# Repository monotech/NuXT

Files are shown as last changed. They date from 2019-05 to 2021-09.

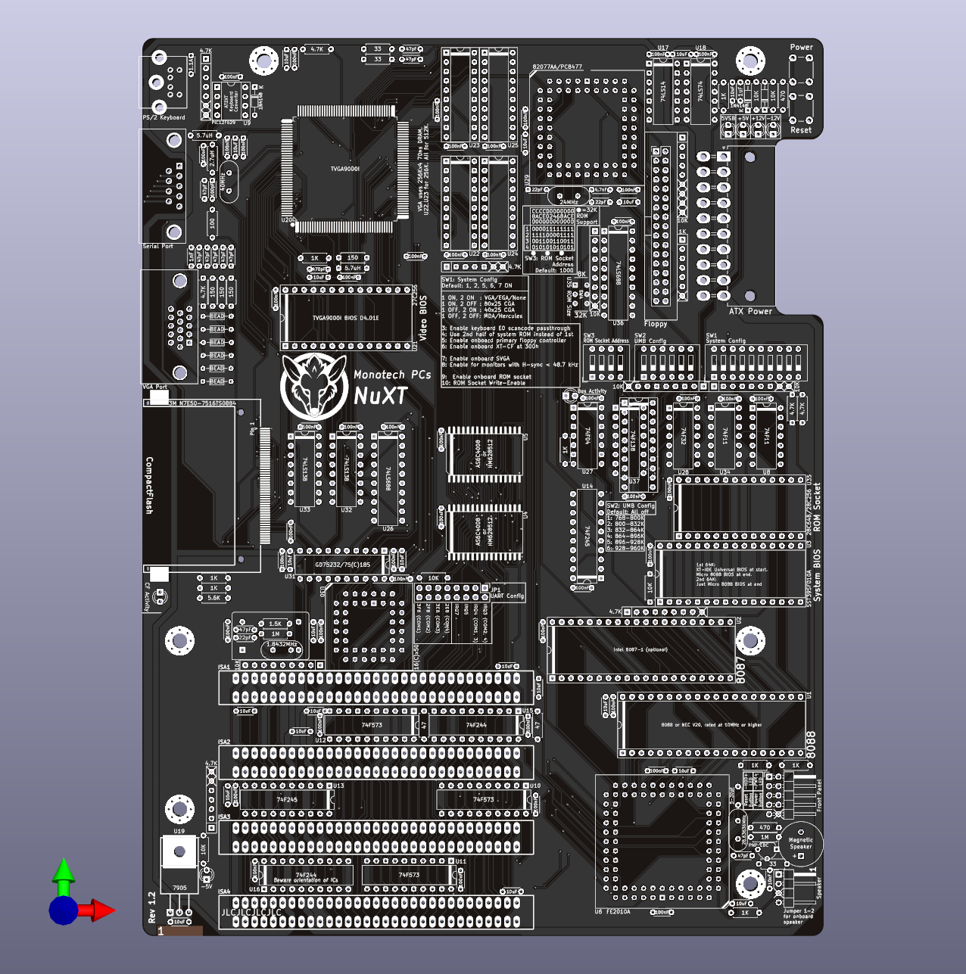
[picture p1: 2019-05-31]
Images/Top bare.png

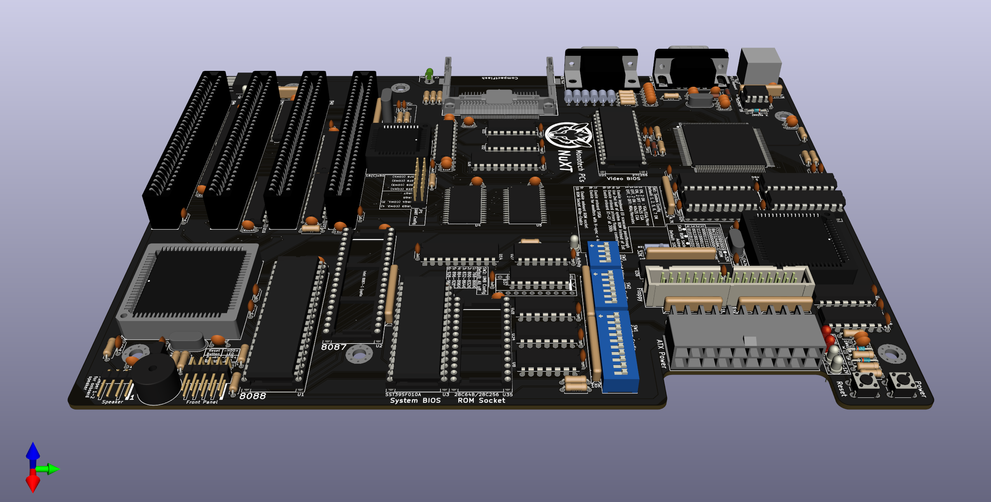
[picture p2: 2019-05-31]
Images/Inner side.png

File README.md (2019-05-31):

Based on schematics by Sergey Kiselev, with some small changes for combining optimization and board layout efficiency:

http://www.malinov.com/Home/sergeys-projects/isa-fdc-and-uart

http://www.malinov.com/Home/sergeys-projects/xt-cf-lite

http://www.malinov.com/Home/sergeys-projects/isa-supervga

https://github.com/skiselev/micro_8088

https://github.com/skiselev/isa8_backplane

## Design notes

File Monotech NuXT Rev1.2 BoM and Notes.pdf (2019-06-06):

## Monotech PCs NuXT Rev1.2 DIY Kit Instructions

These instructions are provided to help with this kit, but they do not show you how to make a good solder joint, or other electronics skills. If unsure, Google it, or ask. As with any DIY kit, warranty cannot be provided.

There are four surface mount components in this kit, with 1.27mm and 0.65mm pitch. Make sure you have good flux and are practiced in SMD soldering.

For troubleshooting, you should have a multimeter at the least; preferably an oscilloscope too.

## Parts list:

ICs | Package | Quantity | Markings/details | Needed for
FE2010A XT Chipset | LCC-84 | 1 | FE2010A*
Trident TVGA9000i VGA Chipset | QFP-160 | 1 | TVGA9000i-* | Onboard VGA
8088 or NEC V20 10MHz+ CPU | DIP-40 | 1 | *8088-1 or NEC D70108*-10
39SF010 128KiB 8-bit Flash (programmed) | DIP-32 | 1 | SST39SF010* (Micro 8088 BIOS + XT-IDE CF)
PIC12F629 Microcontroller (programmed) | DIP-8 | 1 | 12F629* (AT2XT Keyboard Converter) | PS/2 keyboard support
27C256 32KiB EPROM (programmed) | DIP-28-W | 1 | *27C256* (TVGA9000i BIOS D4.01E) | Onboard VGA
128KiB 4-bit 70ns DRAM | DIP-20 | 2 or 4 | *4C4256*70 or *514256*70 | Onboard VGA
512KiB 8-bit Parallel SRAM | SOP-32 450mil | 2 | AS6C4008-*SIN or HM628512*LFP*
PC8477 Floppy Controller | LCC-68 | 1 | PC8477* or 82077AA* | Onboard floppy controller
16550 UART | LCC-44 | 1 | *16*50* | Onboard serial port
75185 RS232 Transceiver | DIP-20 | 1 | *75*185* or GD75232* | Onboard serial port
74LS688 Identity Comparator | DIP-20 | 2 | *74*T688* or *74*S688* or *74F521* | Onboard XT-CF and ROM socket
74F573 Octal Latch | DIP-20 | 3 | *74F573*
74F245 Octal Transceiver | DIP-20 | 2 | *74F245*
74F244 Octal Buffer | DIP-20 | 2 | *74F244*
74F138 3-to-8 Decoder | DIP-16 | 1 | *74F138*
74LS138 3-to-8 Decoder | DIP-16 | 2 | *74*T138* or *74*S138* or *74F138* | Onboard floppy and serial
74LS74 Dual D Flip-flop | DIP-14 | 1 | *74*T74* or *74*S74* or *74F74*
74F32 Quad OR Gate | DIP-14 | 1 | *74F32*
74LS14 Schmitt Hex Inverter | DIP-14 | 1 | *74*T14* or *74*S14* or *74F14*
74F11 Triple 3-input AND Gate | DIP-14 | 2 | *74F11*
74HCT04 Hex Inverter | DIP-14 | 1 | *74*T04*
7905 Negative 5V Linear Regulator | TO-220 | 1 | *7905 | -5V rail at ISA slots
Crystals | Package | Quantity | Markings/details | Needed for
1.8432MHz Crystal | HC49* | 1 | Or a 5V DIP-14 Oscillator instead | Onboard serial port
24MHz Crystal | HC49* | 1 | | Onboard floppy controller
28.63636MHz Crystal | HC49* | 1
40MHz Crystal | HC49* | 1 | | Onboard VGA
Connectors | Package | Quantity | Markings/details | Needed for
2x31-way 2.54mm Through-hole edge connector | | 4 | | ISA slots
3M CompactFlash connector | | 1 | 3M N7E50-7516TS0884 | Onboard XT-CF
DE-9 Male right-angle connector | | 1 | Supports centred between both pin rows | Onboard serial port
DE-15 Female right-angle connector | | 1 | Supports in-line with middle pin row | Onboard VGA
6-pin Mini-DIN right-angle female connector | | 1 | Preferably purple | PS/2 keyboard support
4-way right-angle pin header | P=2.54mm | 1 | Speaker header | External speaker support
2x5-way right-angle pin header | P=2.54mm | 1 | Front panel header
2x8-way vertical pin header | P=2.54mm | 1 | Serial port jumper block | Onboard serial port
2x10-way right-angle male connector | P=4.2mm | 1 | ATX power connector
2x17-way vertical shrouded pin header | P=2.54mm | 1 | Floppy connector | Onboard floppy controller
DIP-8 Socket | | 1
DIP-20 Socket | | 4 | | Onboard VGA
DIP-28 Socket | | 2 | | Onboard VGA and ROM Socket
DIP-32 Socket | | 1
DIP-40 Socket | | 2
LCC-44 Through-hole Socket | | 1 | | Onboard serial port
LCC-68 Through-hole Socket | | 1 | | Onboard floppy controller
LCC-84 Through-hole Socket | | 1

Switches | Package | Quantity | Markings/details | Needed for
4-way DIP Switch | DIP-8 | 1 | ROM Socket Address | Onboard ROM socket
6-way DIP Switch | DIP-12 | 1 | UMB Config | UMB support
10-way DIP Switch | DIP-20 | 1 | System Config
MS-22D18G2 DPDT Switch | | 1 | U35 ROM Size | Onboard ROM socket
Standard Tactile Switch | | 2 | | Onboard Power / Reset button
Resistors | Package | Quantity | Markings/details | Needed for
33 Resistor | P=7.5mm | 3 | Org-Org-Blk or Org-Org-Blk-Gld
47 Resistor | P=7.5mm | 2 | Yel-Vil-Blk or Yel-Vil-Blk-Gld
100 Resistor | P=7.5mm | 1 | Brn-Blk-Brn or Brn-Blk-Blk-Blk | Onboard VGA
150 Resistor | P=7.5mm | 4 | Brn-Grn-Brn or Brn-Grn-Blk-Blk | Onboard VGA
470 Resistor | P=7.5mm | 2 | Yel-Vil-Brn or Yel-Vil-Blk-Blk
1K Resistor | P=7.5mm | 8 | Brn-Blk-Red or Brn-Blk-Blk-Brn
1.5K Resistor | P=7.5mm | 1 | Brn-Grn-Red or Brn-Grn-Blk-Brn | Onboard serial port
4.7K Resistor | P=7.5mm | 4 | Yel-Vil-Red or Yel-Vil-Blk-Brn
5.6K Resistor | P=7.5mm | 1 | Grn-Blu-Red or Grn-Blu-Blk-Brn | Onboard XT-CF
10K Resistor | P=7.5mm | 5 | Brn-Blk-Org or Brn-Blk-Blk-Red
1M Resistor | P=7.5mm | 2 | Brn-Blk-Grn or Brn-Blk-Blk-Yel
1K Bussed Resistor Array (5 resistors) | SIP-6 | 1 | *102* | Onboard floppy controller
4.7K Bussed Resistor Array (4 resistors) | SIP-5 | 3 | *472*
4.7K Bussed Resistor Array (7 resistors) | SIP-8 | 1 | *472*
10K Bussed Resistor Array (8 resistors) | SIP-9 | 5 | *103*
Capacitors | Package | Quantity | Markings/details | Needed for
22pF Ceramic Capacitor | P=5mm | 4 | 22
47pF Ceramic Capacitor | P=5mm | 10 | 47
100pF Ceramic Capacitor | P=5mm | 1 | 101 | Onboard VGA
470pF Ceramic Capacitor | P=5mm | 1 | 471 | Onboard VGA
1nF Ceramic Capacitor | P=5mm | 1 | 102 | Onboard VGA
10nF Ceramic Capacitor | P=5mm | 1 | 103 | Speaker support
100nF Ceramic Capacitor | P=5mm | 47 | 104
1uF Ceramic Capacitor | P=5mm | 1 | 105
10uF Ceramic Capacitor | P=5mm | 21 | 106
Misc parts | Package | Quantity | Markings/details | Needed for
NuXT Rev1.2 PCB | | 1
2N2907 PNP Transistor | TO-92 | 1 | With EBC pinout (install backwards if CBE) | Speaker support
Magnetic speaker (not piezo) | D=12mm, P=6.5mm | 1 | | Onboard speaker
3mm LED | P=2.54mm | 6 | Preferably Red,Red,Yel,Blu,Grn,Wht | CF activity and power rail LEDs
3mm 2-pin bipolar LED | P=2.54mm | 1 | Red/Green | Bus Activity indicator
1N4148 Diode | DO-34 | 3 | 1N4148
1.1A Resettable Fuse | P=5mm | 1 | | PS/2 keyboard support
Ferrite Bead | P-7.5mm | 6 | | Onboard VGA
2.7uH Inductor | P=7.5mm | 1 | Red-Vil-Gold | Onboard VGA
5.6uH Inductor | P=7.5mm | 2 | Grn-Blu-Gold | Onboard VGA

### - If using 1.8432MHz 5V DIP-14 Oscillator instead of 1.8432MHz Crystal, you can omit: - 1 x 47pF Ceramic Capacitor - 1 x 22pF Ceramic Capacitor - 1 x 1.5K Resistor - 1 x 1M Resistor

- If using an Intel 82077 Floppy Controller instead of the recommended PC8477, a 4.7nF Ceramic Capacitor is also needed.
- The markings in the parts list can contain asterisks as wildcards. For example, some compatible ICs:

### - *74*T32* or *74*S32*: “SN74AHCT32N” - HM628512*LFP*: “HM628512BLFP-7” - *16*50*: “PC16550DV” or “TL16C550CFNR” - *75*185*: “SN75C185N”

- Some 74-series logic can be substituted. 74LS can be substituted for 74F. 74F can usually be substituted for 74ACT.

### Notes:

- For bussed resistor arrays, they only need to be long enough to fill all holes without a cross through them. Holes with a cross are unused, but are there to accommodate larger SIP resistor arrays. Trim legs off of oversized resistor arrays.
- To install long-leaded parts, you may bend the legs before turning the PCB over. But I prefer to leave the legs straight, put a flat soft object like a rigid mousepad on top of the parts, then turn the PCB over. The flat object keeps the parts from falling out, and you have nice straight legs to solder. Works great for ICs especially. Solder one pin of parts first and check they are flush on the other side, adjusting if necessary, before soldering the rest of the pins. Especially important for ICs, DIP switches, and ISA slots.
- For the 7905 regulator, you can bolt the tab down, or solder the tab down. I prefer to solder, but it takes some heat first.
- Ensure polarity is correct for applicable parts.

### - Parts where orientation matters:

- ICs and IC sockets (notch or line on IC must match notch or line on PCB outline)
- LCC IC Sockets (flat corner must match flat corner on PCB outline)
- Bussed resistor arrays (end of resistor array with dot lines up with pin in square on PCB outline)
- Transistor (Flat side of transistor lines up with flat side on PCB, for EBC transistors. Reverse for CBE

transistors) - Diodes - DIP Switches (switch 1 lines up with square pad on PCB) - Voltage regulator (tab lies flat on PCB) - LEDs (flat side faces square pad [negative]) - Parts where orientation does not matter: - Single resistors - Inductors and ferrite beads - Ceramic capacitors - Crystals - Speaker - Pin headers - DPDT switch and tactile switches - ISA slots
- The 74HCT04 IC is preferably a 74*T04, to reduce the power-off glow of the bus activity LED. This will be improved in next version, to prevent the bus activity LED from being lit while powered off (due to stray current from the 5VSB circuit). Using 74LS04 or 74F04 will result in a much more brightly lit activity LED when system is powered off, compared to CMOS parts, which is undesirable. This IC is marked “74F04” on Rev1.2 PCBs.

### Procedure:

1) Read the notes above.
2) For the Front Panel and Speaker headers, remove the pin that is marked with a cross on the associated PCB pad.
3) Install the parts in the correct order so you don’t block yourself from installing the rest of the parts. The order would be:
a. Resistors, inductors, diodes, short crystals, speaker header.

b. VGA IC c. SRAM ICs d. DIP ICs and 7905 regulator e. DIP IC Sockets, Bussed Resistor Arrays, and LEDs f. CompactFlash Connector g. Capacitors and SW4 (U35 ROM Size) h. DIP Switches and Front Panel header i. LCC sockets, Speaker, Transistor, vertical headers j. Connectors k. Tall crystal l. ISA slots
4) Inspect everything carefully, especially for SMD bridges and unsoldered pins.
5) (optional) Clean the flux off. Then dry the PCB, especially under ICs.
6) Insert the socketed ICs.
7) Set DIP switches to default, as detailed on the silkscreen.
8) Test, and check for display output and RAM test. There should be a power-on jingle as soon as the power button is pressed.

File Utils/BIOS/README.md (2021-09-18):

These files are provided for repairing or updating the BIOS on your NuXT v1.2.
They contain Sergey Kiselev's 8088_BIOS Version 0.9.8 (https://github.com/skiselev/8088_bios/tree/master)

It is recommended to update from older versions to 0.9.8 if you use floppy drives, as it fixes some floppy issues.

The NuXT has a 128K flash chip which is split into two halves,
so you effectively have two System ROMs you can switch between with a DIP switch.

The NuXT cannot be bricked by doing something wrong here. The worst that can happen is needing a programmer device to reflash the 128K System ROM chip.

***

The 128K images below are for writing to a Flash ROM IC with a programmer device.
The 8088_BIOS is in both halves of the ROM.

NuXT 128K image - Hybrid (recommended)
- Contains: V20-compatible XT-IDE BIOS in first half, and all-compatible in second half (selectable with DIP switch on NuXT).
- SHA1: F08E5B4535F3B758265380C4431B774A5FB9DB4A
- Last updated: 1 Sep 2021
- Update reason: Updated XT-IDE BIOS to R618 (31st Aug 2021).

NuXT 128K image - V20
- Contains: identical first and second half, with V20-compatible XT-IDE BIOS.
- SHA1: 8A28444BC0F5A41992EACA92667CF80D4FE29C25
- Last updated: 18th Sep 2021
- Update reason: Updated XT-IDE BIOS to R618 (31st Aug 2021).

NuXT 128K image - 8088
- Contains: identical first and second half, with all-compatible XT-IDE BIOS.
- SHA1: DB6ECFA6CE50F35B4DC05F80BBD6B205BCA8B8DA
- Last updated: 18th Sep 2021
- Update reason: Updated XT-IDE BIOS to R618 (31st Aug 2021).

***

WARNING: The below files can be flashed in-system with UFLASH.EXE,
but you must use the correct command-line options, or the flash could be corrupted, and require a programmer device and the 128K image to fix.

If you don't have a programmer device handy in case you make a mistake, do not flash anything if the system is working as expected,
If you just wish to update the System BIOS, you needn't reflash the entire ROM. And vice-versa for just updating the XT-IDE BIOS.

The provided images are padded so the data ends up at the correct location, and old data is overwritten if a programmed BIOS is smaller than the previous one.
If you are programming a customized XT_IDE BIOS, you should pad the end of the file with FF's until it's 32768 bytes, then use the same flashing command as the XT-IDE BIOS below.

UFLASH can provide a delay before flashing, to allow switching to and flashing the other half of the System ROM while the system is running.
This is useful if you wish to change the XT-IDE BIOS from V20 to 8088 type (the system will hang if you are using an 8088 CPU and the V20-compatible XT-IDE BIOS tries to initialize).
To add a delay of 30 seconds, add the following to the end of the command line: -t 30
(The timer is only accurate on 4.77MHz 8088. Set a longer timer value for faster CPUs)

uFlash is Sergey's XiFlash tool, adapted by Aitor Gomez to work on Micro 8088 and NuXT (https://github.com/spark2k06/micro_8088/tree/master/BIOS)

*** System BIOS ***

NuXT System BIOS image (BIOS098.BIN)
- Bare Micro 8088 BIOS image by Sergey Kiselev
- UFLASH Command: UFLASH -p -i BIOS098.BIN -a F800
- SHA1: 712F9D12C2F67B4FA86B582EB8C98ACBB5E5400D
- Last updated: 17th May 2020
- Update reason: Updated to 0.9.8

***

*** XT-IDE BIOS ***

XT-IDE BIOS image - V20-CPU-compatible (XTIDEV20.BIN)
- Contains: V20-compatible XT-IDE BIOS, configured for the NuXTv1.2 - faster, but not compatible with 8088 CPU
- UFLASH Command: UFLASH -p -i XTIDEV20.BIN -a F000
- SHA1: 1030B38BC6BA17A8A6F463DCAA1378289CCFD2E0
- Last updated: 18th Sep 2021
- Update reason: Updated XT-IDE BIOS to R618 (31st Aug 2021).

XT-IDE BIOS image - All-CPU-compatible (XTIDE88.BIN)
- Contains: all-compatible XT-IDE BIOS, configured for the NuXTv1.2 - slower, but works with all CPUs
- UFLASH Command: UFLASH -p -i XTIDE88.BIN -a F000
- SHA1: 205AD526669D371AFCD53FD883090DB238DCDF12
- Last updated: 18th Sep 2021
- Update reason: Updated XT-IDE BIOS to R618 (31st Aug 2021).

***

*** Entire ROM (System BIOS and XT-IDE BIOS) ***

NuXT 64K image - V20 (098_NV20.BIN)
- Contains: V20-compatible XT-IDE BIOS, configured for the NuXTv1.2 - faster, but not compatible with 8088 CPU
- UFLASH Command: UFLASH -p -i 098_NV20.BIN -a F000
- SHA1: 539255278C08D5E9B152EBF442620CB9583BFD32
- Last updated: 18th Sep 2021
- Update reason: Updated XT-IDE BIOS to R618 (31st Aug 2021).

NuXT 64K image - 8088 (098_8088.BIN)
- Contains: all-compatible XT-IDE BIOS, configured for the NuXTv1.2 - slower, but works with all CPUs
- UFLASH Command: UFLASH -p -i 098_8088.BIN -a F000
- SHA1: A8BE7594E317C050F9B1B5C7CED91B72390143A7
- Last updated: 18th Sep 2021
- Update reason: Updated XT-IDE BIOS to R618 (31st Aug 2021).

***

Note1: When XT-IDE BIOS version R606 came out, a bug was fixed relating to incorrectly addressing small CF cards in CHS mode when they support LBA.
NuXT v1.2 boards all shipped with an XT-IDE BIOS version older than R606.

As a consequence of the bug fix, CF cards formatted on an XT-IDE BIOS older than R606 will not be bootable in an R606 or later BIOS, and vice versa.

If your CF card fails to boot, I recommend updating the XT-IDE BIOS version in all XT-IDE devices you own where you wish to swap the CF card between devices,
and then reformat the CF cards to the new format.

The easiest way to do this, is to backup the files off the card, then prepare it in a system with the updated XT-IDE BIOS, as per instructions for preparing
a CF card, described in any NuXT user manual.

Note2: The files here are intended for the NuXT v1.2, which has an XT-CF interface at I/O address 300h.
They are not interchangeable with the NuXT v2.0, which has an XT-IDE Rev2 interface at I/O address 170h. Only the XT-IDE BIOS portion of these images differ.

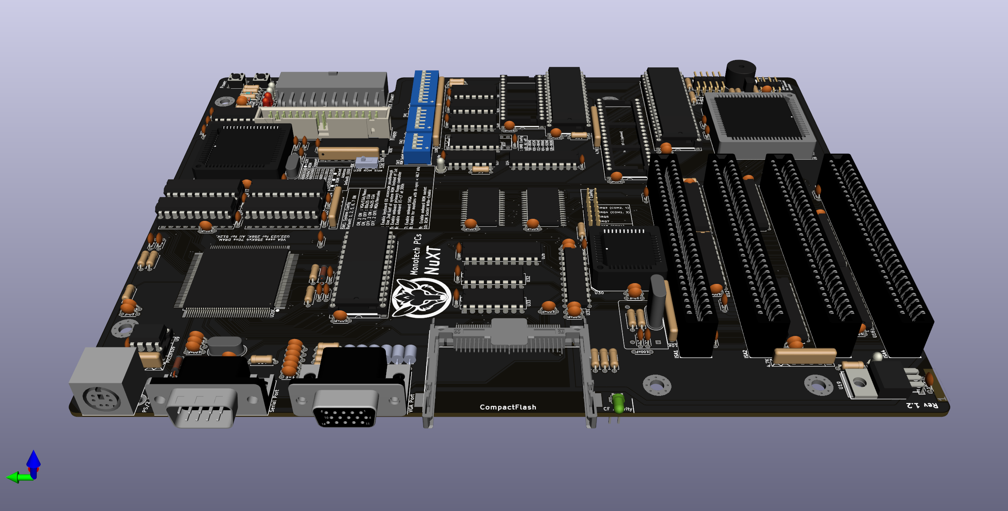
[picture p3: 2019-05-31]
Images/Port side.png

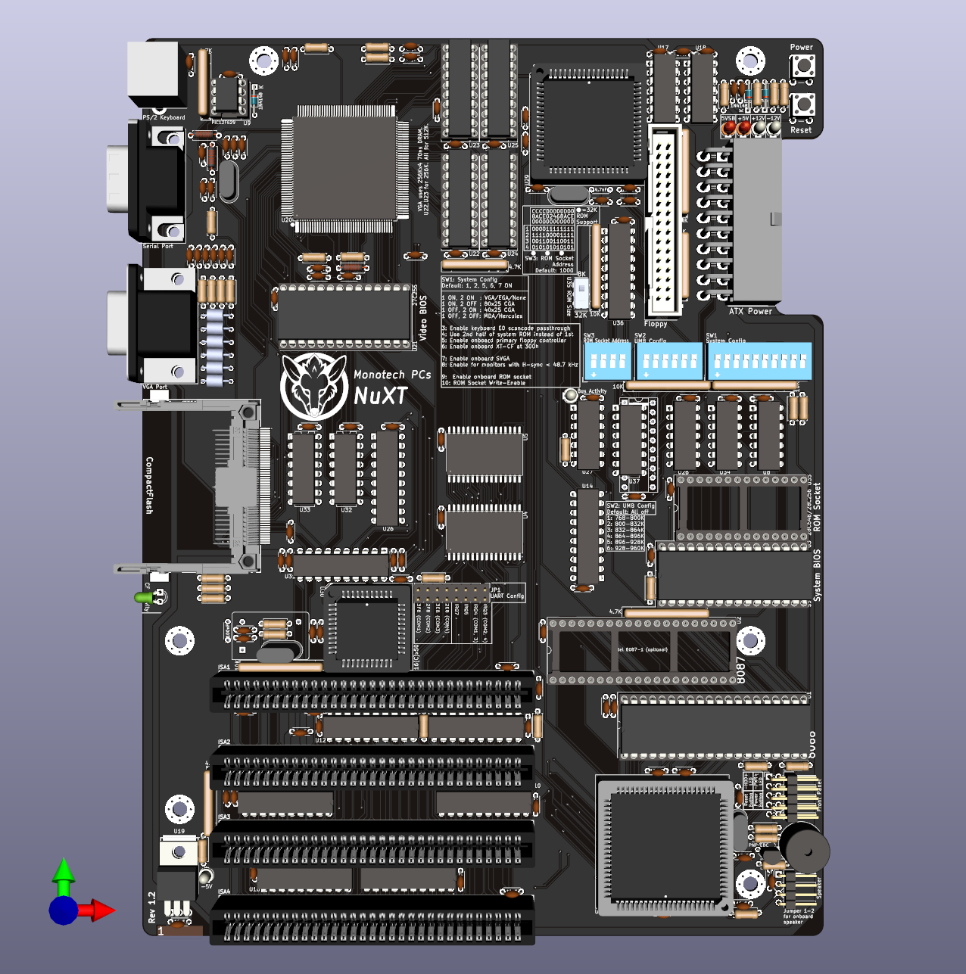
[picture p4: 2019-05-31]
Images/Top.png

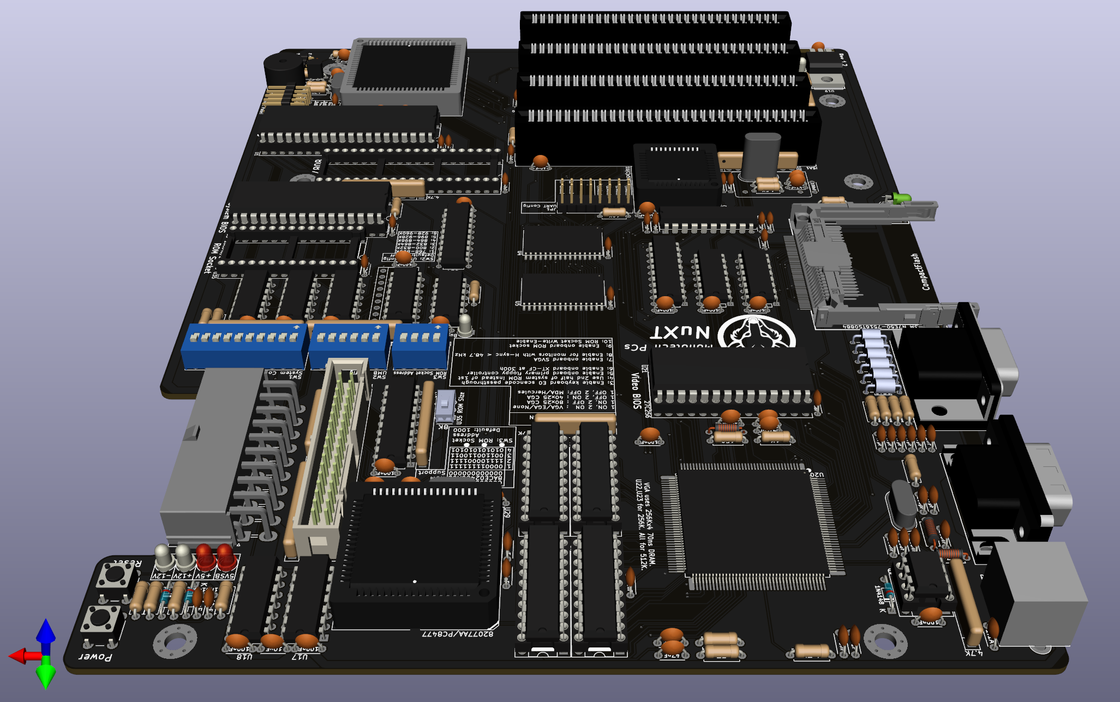
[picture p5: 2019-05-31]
Images/Top side.png

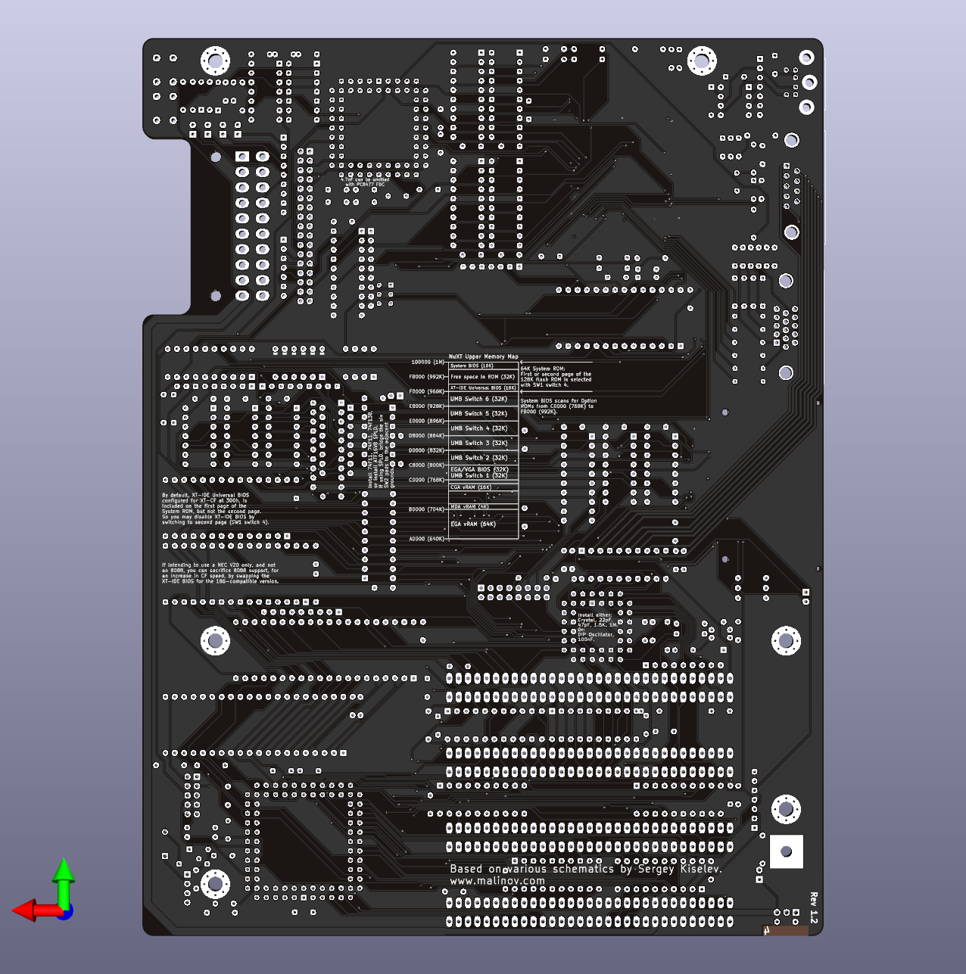
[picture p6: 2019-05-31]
Images/Bottom.png

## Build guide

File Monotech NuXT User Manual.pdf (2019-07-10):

# Monotech PCs

# NuXT

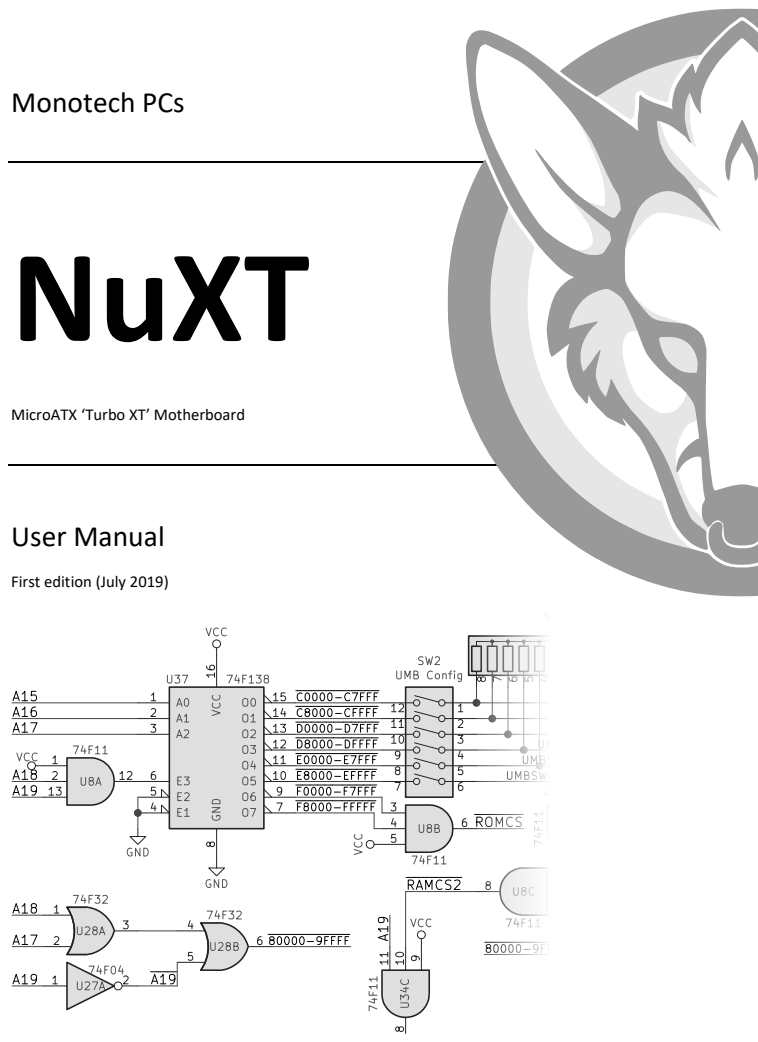
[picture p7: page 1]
User Manual

MicroATX ‘Turbo XT’ Motherboard

First edition (July 2019)

Notes:

The schematic of the NuXT, and the System BIOS, are based on various open-source projects by Sergey Kiselev. I highly recommend checking out his projects at www.malinov.com.

This is an open-source project. The source files are at github.com/monotech/NuXT

Terminology:

- ROM – Read-only memory: Includes System BIOS and Option ROMs. Also known as firmware.
- RAM – Random-access memory: Temporary storage of running program data.
- Memory – Often refers to RAM, but can also refer to ROM.
- Memory address – the location of some RAM or ROM in the 1MiB memory address space.
- System ROM – Located in Upper Memory, the System ROM contains the System BIOS, and optionally, some Option ROMs
- System BIOS – The first program that the CPU runs. Initializes the system and boots an OS.
- Option ROM – Also known as ‘Boot ROM’ or ‘BIOS Extension’. This is a program stored in ROM that adds more BIOS functions, before the OS loads, allowing extended hardware support.
- Conventional Memory – RAM located between 0K and 640K. Usable by DOS and all software.
- Upper Memory – RAM or ROM located between 640K and 1024K.
- High Memory – RAM above 1024K. Not supported by NuXT; 286 and higher PCs only.
- UMBs – Upper memory blocks: RAM that has been placed within upper memory, which can be used by drivers, TSRs, and DOS itself.
- Hardware resource – I/O Ports, Memory address ranges, and IRQs are all hardware resources. If multiple devices share one, it can cause a resource conflict and instability.

# Contents

# Features

### - IBM PC/XT Compatible Motherboard - MicroATX form factor. 244 x 185 mm - Switchable 4.77MHz, 7.16MHz, and 9.55MHz CPU clock - 640K Conventional Memory - Up to 192K Upper Memory Blocks - Dual 64K System ROM – switchable with DIP switch

- System BIOS is Sergey Kiselev’s Micro 8088 BIOS.
- Up to 32K usable as Option ROM space. XT-IDE BIOS uses half.

### - Option ROM socket with write support - PS/2 Keyboard Port

- Implemented with AT to XT converter in a microcontroller.

### - ATX power input

- -5V rail not needed. Is generated onboard for ISA slots.
- 20-pin connector. 24-pin connectors will fit too.

### - Four 8-bit ISA Slots

- Three of the four slots can fit 16-bit cards.

- Onboard peripherals: - Advanced floppy controller - Supports most floppy drives, including HD and ED - Supports single-density (FM) disks - Serial port - 16550 UART with FIFO buffer - Selectable I/O address and IRQ - CompactFlash interface - Located at I/O port 300h - Super VGA graphics - Up to 1024 x 768 resolution - Up to 256 colours

# Compatibility

- CPU: 8088, NEC V20, or compatible
- Must be at least 10MHz rated. Set the CPU speed lower in the System BIOS if it isn’t.
- 8088 provides greater replication of original IBM PC, due to identical speed.
- NEC V20 provides roughly 20% more performance, and 80186 instructions.
- FPU: Intel 8087
- Optional. Only used by applications specifically programmed for it.
- Must be at least 10MHz rated. Set the CPU speed lower in the System BIOS if it isn’t.
- System ROM: SST39SF010A 128K Flash ROM
- First half: XT-IDE Universal BIOS at the start, configured for XT-CF at 300h, Micro 8088 BIOS at the end. Second half: Just Micro 8088 BIOS at the end.
- Full 128K file to flash with programmer: github.com/monotech/NuXT
- Option ROM Socket: 28C64B or 28C256 EEPROM, or 27C64
- Optional, for if another Option ROM is desired.
- Video RAM: Two or four 256Kx4bit 70ns DRAMs
- Two ICs, in the sockets closest to the VGA IC, for 256K. All four ICs for 512K.
- Examples of compatible DRAMs are: TC514256AP-70, MT4C4256-7, MCM514256AP70, MB81C4256A-70P.
- Video BIOS: 27C256
- Programmed with TVGA9000i BIOS D4.01E.
- AT to XT keyboard converter: PIC12F629 Microcontroller
- Programmed with AT2XT firmware: vcfed.org/forum/showthread.php?26426
- UART: 16550 or compatible
- Floppy controller: National Instruments PC8477* or Intel 82077*
- PC8477BV-1 is recommended.
- If an Intel controller is used, the adjacent 4.7nF capacitor must be installed.
- The System BIOS supports booting from floppy disks. The correct drive type must be selected in the BIOS Setup. Supports booting from 360K, 720K, 1.2M, 1.44M, 2.88M.
- The Trident TVGA9000i SVGA chip supports standard VGA modes, plus SVGA modes, as well as MDA, CGA, Hercules, EGA. Some modes require specific support for the chip, such as a driver.
- Some SVGA modes require 512K VRAM:
VGA mode | 256K | 512K
640x480, 16 colour | Yes | Yes
640x480, 256 colour | | Yes
800x600, 16 colour | Yes | Yes
800x600, 256 colour | | Yes
1024x768, 4 colour | Yes | Yes
1024x768, 16 colour | | Yes

# System BIOS

### The NuXT uses Sergey Kiselev’s Micro 8088 BIOS. This is IBM PC/XT compatible, with

some handy features.

### To enter the BIOS Setup, press F1 during the RAM test. The setup utility will then run

when the RAM test completes.

### You may then press ‘H’ to see available commands, and any time you may press ‘R’ to

return to the main menu.

### - ‘C’ – Set startup CPU speed - 4 – 4.77MHz - 7 – 7.16MHz - 9 – 9.55MHz - ‘F’ – Change first floppy drive type - 0 – None

- 1 – 360K 5 ¼”
- 2 – 1.2M 5 ¼”
- 3 – 720K 3 ½”
- 4 – 1.44M 3 ½”
- 6 – 2.88M 3 ½”

### - ‘G’ – Change second floppy drive type - As above - ‘P’ – Display current settings on screen - ‘W’ – Write current settings to ROM

- BIOS settings are saved in the System ROM. No battery is needed.

### - ‘Q’ – Exit without saving changes

### At any time while in DOS, you may switch CPU speeds with a hotkey. This works in

some applications, but not others. It always works at the DOS prompt.

### 4.77MHz: Ctrl, Alt, Numpad –

### 7.16MHz: Ctrl, Alt, Numpad *

### 9.55MHz: Ctrl, Alt, Numpad +

# Board Layout – NuXT Rev1.2

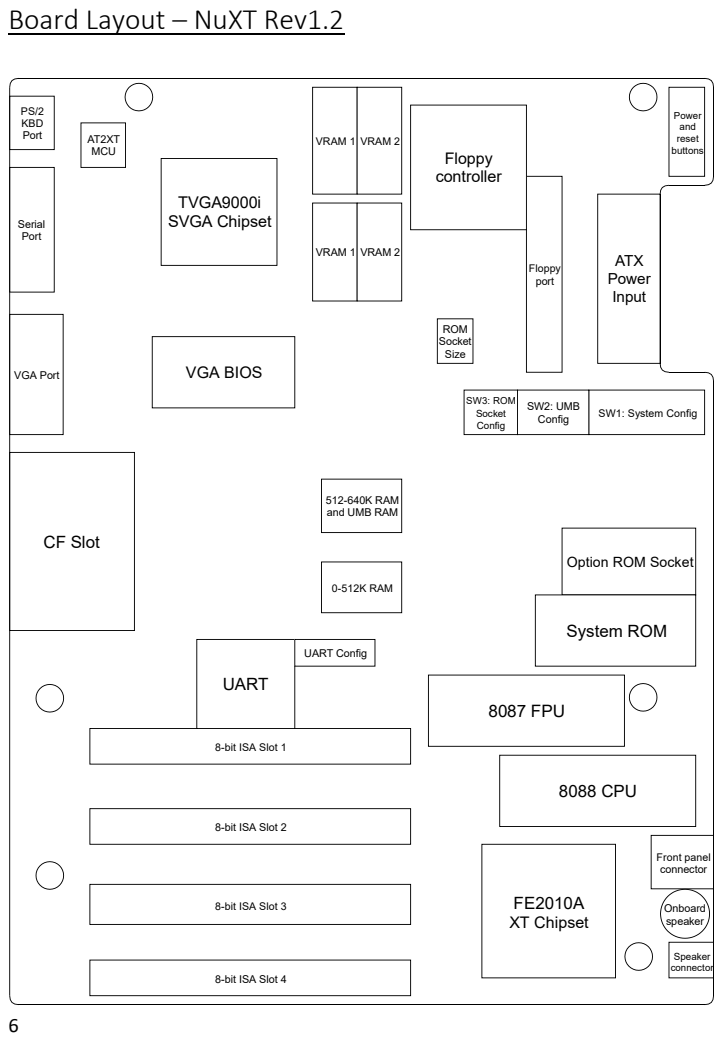
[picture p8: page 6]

# Connectors

Front panel connector: | Speaker connector:

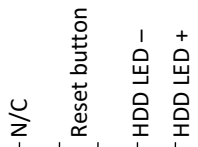
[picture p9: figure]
HDD LED

| Jumper pins 1 and 2 to enable the onboard speaker. Otherwise, connect a speaker to pins 1 and 4.
| This is slightly different to most 4-pin speaker connectors. They usually have +5V and Speaker output. This has GND and Speaker output. Take note if connecting to the “PC Speaker” input on sound cards, to not cause a short of +5V to GND.

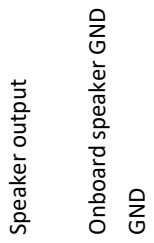
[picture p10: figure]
Speaker output; Onboard speaker GND; GND

### Serial port configuration jumper: – Default: COM1

Remove both jumpers to disable the onboard serial port.

To enable the serial port, put a jumper on an I/O address, and on an IRQ line.

Ensure the setting doesn’t conflict with any other devices in the system.

COM designation | I/O Address | IRQ Line
COM1 | 3F8 | IRQ4
COM2 | 2F8 | IRQ3
COM3 | 3E8 | IRQ4
COM4 | 2E8 | IRQ3

# – HDD LED + Power LED Power LED +

# – Power button Reset button

1. C0000-C8000 (768-800K)
2. C8000-D0000 (800-832K)
3. D0000-D8000 (832-864K)
4. D8000-E0000 (864-896K)
5. E0000-E8000 (896-928K)
6. E8000-F0000 (928-960K)

# DIP Switches

### SW1: System Config – Default: 1, 2, 5, 6, 7 ON

Switches 1 and 2 set the video card type:

3. Enable keyboard E0 scancode passthrough for the AT to XT keyboard converter.
4. Use secondary System ROM.
- When switched ON, this will use the second half of the 128K ROM chip as the System ROM instead of the first half.
5. Enable onboard floppy controller.
- Switch off if using a floppy controller card.
6. Enable onboard CF card interface.
- Switch off if another device needs to use I/O address 300h.
- If switching off, you should also switch to secondary System ROM, which by default doesn’t contain XT-IDE Universal BIOS. This will speed up boot time.
7. Enable onboard VGA.
- Switch off if using any video card.
8. Enable for VGA monitors with H-sync less than 48.7 kHz.
9. Enable onboard Option ROM socket.
10. Allow writing to the onboard Option ROM socket.

### SW2: Upper Memory Blocks Config – Default: all OFF

### These switches put 32K blocks of usable RAM into Upper Memory. There must not be any Option ROMs or ISA card RAM at the selected locations, or you’ll get instability or inability to boot. This UMB RAM can be used for TSRs, Drivers, and DOS itself, to free

up conventional memory. More on that on page 10/11.

Video card type | 1 | 2
VGA or EGA or None | ON | ON
80x25 CGA | ON | OFF
40x25 CGA | OFF | ON
1 2 3 4 5 6 7 8 9 10 | MDA or Hercules | OFF | OFF

O
N

1 2 3 4 5 6

O
N

### SW3: Option ROM Socket Memory Address – Default: 2 ON

This switch sets the starting memory address of the Option ROM socket.

All addresses are compatible with an 8K E(E)PROM (28C64B or 27C64).

Only the specified addresses are compatible with 32K EEPROMs (28C256).

27C256 is not compatible, as it has a different pinout.

Memory address | 1 | 2 | 3 | 4 | 32K support
C0000 | OFF | OFF | OFF | OFF | YES
C2000 | OFF | OFF | OFF | ON
C4000 | OFF | OFF | ON | OFF
C6000 | OFF | OFF | ON | ON
C8000 | OFF | ON | OFF | OFF | YES
CA000 | OFF | ON | OFF | ON
CC000 | OFF | ON | ON | OFF
CE000 | OFF | ON | ON | ON
D0000 | ON | OFF | OFF | OFF | YES
D2000 | ON | OFF | OFF | ON
D4000 | ON | OFF | ON | OFF
D6000 | ON | OFF | ON | ON
D8000 | ON | ON | OFF | OFF | YES
DA000 | ON | ON | OFF | ON
DC000 | ON | ON | ON | OFF
DE000 | ON | ON | ON | ON

### U35 ROM Size: This switch must be set to 8K (28C64B/27C64) or 32K (28C256)

depending on what size ROM you have installed in the Option ROM Socket.

### Beware that the addresses below C8000 (above on the table), are used by the Video

BIOS if you’re using VGA or EGA. See next page for clarification.

1 2 3 4

O
N

# Upper Memory Map

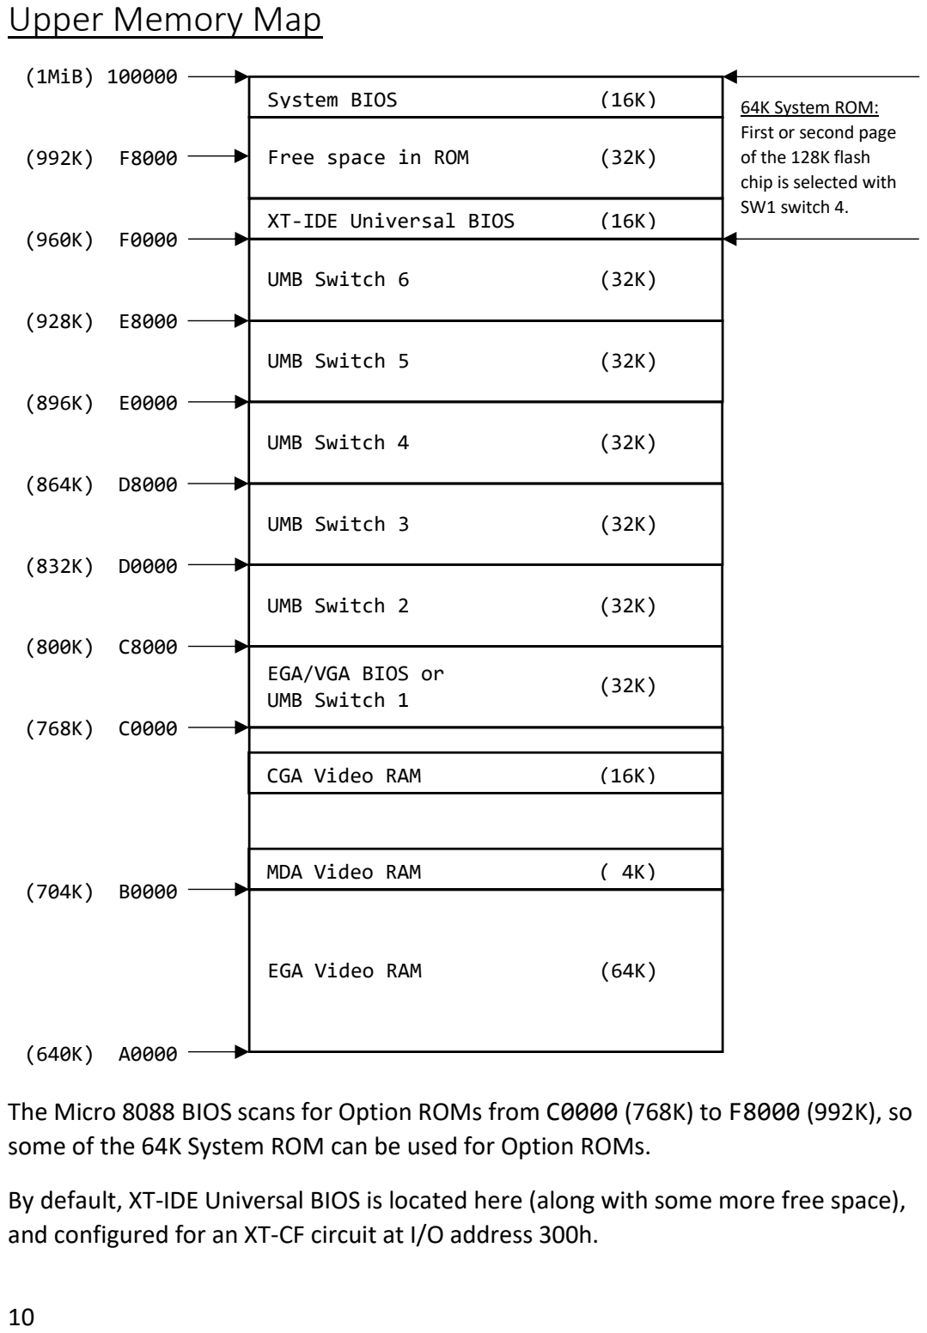
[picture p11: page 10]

### The Micro 8088 BIOS scans for Option ROMs from C0000 (768K) to F8000 (992K), so

some of the 64K System ROM can be used for Option ROMs.

By default, XT-IDE Universal BIOS is located here (along with some more free space), and configured for an XT-CF circuit at I/O address 300h.

System BIOS | (16K)
Free space in ROM | (32K)
XT-IDE Universal BIOS | (16K)
UMB Switch 6 | (32K)
UMB Switch 5 | (32K)
UMB Switch 4 | (32K)
UMB Switch 3 | (32K)
UMB Switch 2 | (32K)

EGA/VGA BIOS or
UMB Switch 1
EGA Video RAM | (64K)
CGA Video RAM | (16K)
MDA Video RAM | ( 4K)

(1MiB) 100000

(992K) F8000

(960K) F0000

(928K) E8000

(896K) E0000

(864K) D8000

(832K) D0000

(800K) C8000

(768K) C0000

(704K) B0000

(640K) A0000

64K System ROM:
First or second page
of the 128K flash
chip is selected with
SW1 switch 4.

(32K)

# Upper Memory Blocks DOS Setup

To use the upper memory blocks in DOS, you need a driver. USE!UMBS 2.20 is the recommended driver, along with DOSMAX to move DOS to upper memory. This configuration should leave you with only 10K Conventional Memory used. DOS 5.0 or later is required.

Ensure there are no other cards that use the upper memory ranges that you’ve enabled as RAM on the SW2 DIP switch.

Examples of cards that would conflict with some of the SW2 switches:

- EMS memory cards. These usually have a 64K block of upper memory used as their window.
- Ethernet cards. Some Ethernet cards are memory-mapped. Check the Ethernet card configuration.
- Cards with Option ROMs. Some examples:
- Hard Drive controllers
- HD floppy controllers
- Ethernet card Boot ROMs
- EGA and VGA cards, including the onboard VGA

For a graphical representation of the upper memory area, see the NuXT Upper Memory chart to the left. This is also on the back of the motherboard itself.

To add the USE!UMBS 2.20 driver to your CONFIG.SYS, add the following two lines to the start of the file, after any FILES or BUFFERS lines: (Find USE!UMBS 2.20 at github.com/monotech/NuXT)

DOS=UMB
DEVICE=C:\USE!UMBS.SYS C800-F000
- “C800-F000” specifies the range of upper memory that can be used as RAM (take a zero off the end). Ensure this matches what you have SW2 set to.
- C800-F000 matches switches 2 through 6 being ON.
- If switch 3 through 5 was ON instead, it would be D000-E800. Refer to the chart on the left.

Then add DOSMAX to your CONFIG.SYS to move DOS into upper memory. Add the following line right after USE!UMBS.SYS: (This assumes you have all the DOSMAX files copied to C:\UTILS\DOSMAX)

DEVICE=C:\UTILS\DOSMAX\DOSMAX.EXE /R+ /N+ /P-

And the following line at the end of CONFIG.SYS:

SHELL=C:\UTILS\DOSMAX\SHELLMAX.COM C:\COMMAND.COM C:\ /E:256 /P

# Preparing a CompactFlash card for DOS

This guide applies to any DOS PC, not just the NuXT.

You will need:

- A modern PC, with software that can wipe a drive by filling with zeroes
- A USB card reader with a CF slot
- A DOS 6.22 floppy. Boot Disk or Disk 1.
- (optional) A DOS 3.x floppy if you wish to use DOS 3.x. The DOS 6.22 floppy is still needed.

To prepare a CF card for MS-DOS 6.22:

1. Wipe the CF card on a modern PC. Software such as a partition editor, or ‘dd’ under Linux/macOS, can do this. You want to write zeroes to the whole card. “Formatting” a card is not wiping it.
2. Put the CF card into the vintage PC, turn the PC on, and boot from a DOS 6.22 floppy.
3. Run FDISK /MBR
4. Run FDISK, and create any partitions.
5. Reboot and boot from the same DOS floppy.
6. Run FORMAT C: /S
7. Done! The CF card is now bootable with minimal DOS 6.22. Feel free to install the rest of DOS, or move the CF card to a modern PC to transfer apps and games.

To prepare a CF card for DOS 3.x:

1. Wipe the CF card on a modern PC. Software such as a partition editor, or ‘dd’ under Linux/macOS, can do this. You want to write zeroes to the whole card. “Formatting” a card is not wiping it.
2. Put the CF card into the vintage PC, turn the PC on, and boot from a DOS6.22 floppy.
3. Run FDISK /MBR
4. Run FDISK, and create one partition. 32MB max. 512MB max for MS-DOS 3.31.
5. Reboot and boot from a DOS 3.x floppy.
6. Run FORMAT C: /S
7. If you’d like more partitions, run DOS 3.x FDISK now to create them.
8. Done! The CF card is now bootable with minimal DOS 3.x. Feel free to install the rest of DOS, or move the CF card to a modern PC to transfer apps and games.

If you’d like to back up or clone your kitted out CF card to another of identical size, you can use software such as Win32DiskImager, or ‘dd’ in Linux/macOS.

# Structure of the NuXT System ROM

The NuXT System ROM is a 128KiB Flash ROM (SST39SF010A), split into two pages, with the selected page (SW2 Switch 4) located at F0000 to 100000 (960K to 1M).

We effectively have two 64K System ROMs that we can switch between.

You may wish to create another for various reasons, or insert more Option ROMs into it. A common reason to alter the System ROM is to change XT-IDE Universal BIOS from the 8088-compatible version to the faster 186-compatible version that requires a NEC V20. By default, the NuXT comes with the 8088-compatible version, so users may use an 8088 if they wish, and also because the speed difference isn’t hugely noticeable.

The System ROM must contain the System BIOS for the NuXT to work at all. The NuXT uses Sergey Kiselev’s Micro 8088 BIOS. This BIOS has a settings menu, and all settings are saved to the System ROM itself, negating the need for a battery.

Option ROMs may be placed in the first 32K of each half of the ROM chip, at 4K boundaries.

The hardware is capable of flashing the System ROM in-system from DOS, but requires a software utility to be written.

If you’d like to alter the System ROM in a hex editor on a modern PC, I recommend acquiring the pre-made 128K ROM image from github.com/monotech/NuXT. This is ready to program with a programmer device such as a universal programmer or a PCI Ethernet card with a 32-pin socket.

This pre-made image is structured like this, and it is recommended to keep to that structure:

- Start of the file – XT-IDE Universal BIOS, configured for XT-CF at 300h.
- Empty space (FF’s)
- C000 – FFFF – Micro 8088 BIOS

--- this is the 64K boundary where the ‘secondary System ROM’ starts ---

- 10000 – 1BFFF – Empty space (FF’s)
- 1C000 – 1FFFF – Micro 8088 BIOS

One alternative would be to place the 186-compatible XT-IDE BIOS (configured for XT-CF at 300h) at the start of the first half, and the original 8088-compatible XT-IDE BIOS at the start of the second half. This would allow switching to an 8088-compatible BIOS if switching to an 8088 CPU from a NEC V20.

The default layout is so you may disable XT-IDE Universal BIOS with a DIP switch, in case you aren’t using the onboard XT-CF. If you don’t have a CF card installed, but XT-IDE Universal BIOS is still active, there will be a delay at boot as XT-IDE Universal BIOS tries to detect a CF card.

# Configuring XT-IDE Universal BIOS (XUB)

Most of this applies to XUB in general, not just on the NuXT.

XUB can be found at xtideuniversalbios.org/binaries

XUB is a hard disk Option ROM, that supports a wide range of HDD controllers and HDDs, including special modern XT controllers such as “XT-IDE” and “XT-CF”.

The NuXT has an XT-CF circuit for the CF slot, and uses XUB to detect and access the drive. XUB is located in the 32K half of the System ROM that is scanned by the System BIOS for Option ROMs. The IDE I/O Address for the NuXT’s onboard XT-CF, is fixed at 300h.

You may wish to reconfigure XUB for the following reasons:

- Update to a newer version that may fix issues or increase compatibility.
- Change to the 186-compatible version, which is faster, but requires a NEC V20.
- Add more controllers for XUB to handle, such as ones on a card you add to the NuXT, including XT-IDE, XT-CF, and a “16-bit IDE interface in 8-bit mode” (supports CF cards only).

XUB releases have the following files:

Filename | Minimum CPU | Size | Boot menu
IDE_XT.BIN | 8088 | 8K
IDE_XTL.BIN | 8088 | 12K | Yes
IDE_XTP.BIN | NEC V20 | 8K
IDE_XTPL.BIN | NEC V20 | 12K | Yes
IDE_AT.BIN | 286 | 8K
IDE_ATL.BIN | 286 | 12K | Yes
IDE_386.BIN | 386 | 8K
IDE_386L.BIN | 386 | 12K | Yes

The higher minimum CPU images will generally provide greater disk performance.

The 12K releases may be only 10K sometimes. Either way, they won’t fit on an 8K ROM.

The regular 8K ROM will boot from the first hard drive, unless you press ‘A’ to boot from the first floppy drive instead. This can be swapped. The 12K ROM has a boot menu, which lets you choose from any drive to boot from. This may swap drive letters to please DOS, and isn’t always hassle-free.

Since the NuXT System ROM has 32K of free space for Option ROMs, you can freely use the 12K release here.

The higher CPU versions can work with even higher CPUs. For example, the 186-compatible version will work on a 286 just fine, and the 8088-compatible will work with all CPUs.

XTIDECFG.COM – Configuration utility. Used to alter the XUB BIOS images, and to flash any image (not just XUB) to an EEPROM, in-system. Can be run in DOSBOX to alter the images on a modern PC, and then flash to EEPROM with a programmer.

When reconfiguring an XT-IDE or XT-CF card, use the following table to determine action:

Desired change | Must change switches on card | Must configure and re-flash XUB
Change Boot ROM Address | Yes | No
Change IDE I/O Address | Yes | Yes
Change XT-IDE HiSpeed mode | Yes | Yes
Change other XUB settings | No | Yes

The Boot ROM address for XUB on the NuXT is well out of the way of other devices that use upper memory, because it’s stored in the System ROM above F0000 (960K). See page 10 for clarification.

HiSpeed mode (also known as “Chuck mod”, named after Chuck(G) on VCF who discovered it) only applies to XT-IDE cards, not XT-CF. It improves disk performance, but is incompatible with a small number of systems.

If using in a 386 or up, once everything is working how it should, you should enable ROM Shadowing in your System BIOS Setup, for the location of the XUB Boot ROM, to improve disk performance.

To configure XUB, do the following:

1. Run XTIDECFG.COM from DOS.
2. Select ‘Load BIOS from file’. Select an appropriate XUB image as per previous page.
3. Select ‘Configure XTIDE Universal BIOS’.
4. Set the number of IDE controllers to whatever number you’d like XUB to handle. Default is 1. If configuring more than 2, you must enable ‘Full operating mode’.
5. You can then enter each of the IDE controller menus, and set the Device Type, and I/O address. You can usually leave ‘Master Drive’ and ‘Slave Drive’ as default, and XUB will autodetect drives at boot. Choose from the following Device Types:
- 16-bit ISA/VLB/PCI – this is a standard IDE interface as seen on motherboards, Multi-I/O cards, and some sound cards. Only works in a 286 and up.
- 32-bit VLB/PCI IDE – this is for 486 machines and up with those interfaces.
- XTIDE rev 1 – this is an XT-IDE card in Compatibility Mode.
- XTIDE rev 2 or modded rev 1 – this is an XT-IDE card in HiSpeed mode.
- XT-CF PIO8 – this is an XT-CF, as seen built onto the NuXT, or as a card.
- For the other controllers, refer to xtideuniversalbios.org
6. Go back, and enter Boot Settings. Here, you can change Display Mode, and the default drive.
7. Go back to the main menu. You can now either save the XT-IDE configuration to the original ROM image you selected at the start, or you can flash it if you’re doing this in-system.
- Flashing the XT-IDE BIOS in-system can be done on XT-IDE and XT-CF cards, but not on the NuXT’s System ROM unless a special utility is written.
- To flash the EEPROM, you must have the card switched to enable writes.
- Ensure the EEPROM Type and Address are correct, and choose Start Flashing.
- If it fails, and you are sure the above settings are correct, change the Page Size to 64 bytes, and then each of the other Page Size settings, until it works. Some systems need this setting set differently.

# Troubleshooting

Here are a few steps to take if you encounter trouble with the NuXT:

- Beeping on and off and not booting up – general error
- Bad CPU or FPU, bad RAM, or bad logic
- Reseat the ICs
- To disable onboard RAM in order to try a RAM card, you can disconnect pin 19 of U14 from the board, and connect the pin to +5V (pin 20).
- Shorted ISA bus lines
- Check for debris in the ISA slots
- Remove all ISA cards
- Check CF slot for bent pins
- You hear the POST jingle, but there is no display
- VGA issue, bad connection, or incompatible display
- Try another monitor
- Disable the onboard VGA and try another video card
- Reseat the VRAM and Video BIOS ICs
- Check your VGA cable for bent pins
- Keyboard issues
- Check your keyboard’s mini-DIN connector for bent pins
- Enable keyboard E0 scancode passthrough (SW1 switch 3)
- Try another keyboard. A small number aren’t compatible
- Ensure the PIC12F629 microcontroller is programmed with AT2XT
- Serial port unreliability
- This was an issue with all of the Rev1.0 NuXT, and one of the three Rev1.1 boards produced (since been recycled). Please report it if you encounter it with the Rev1.2.
- Reseat the UART IC
- Ensure jumper settings are correct, and don’t conflict. Refer to page 7
- Incompatible serial card. Some work better than others with the NuXT. The serial port on the DeluxeFloppy card is not suitable for use with the NuXT.
- Try another serial card. A common multi-I/O card perhaps.
- CF card not detected, detected with a corrupted name, or has intermittent corruption issues
- Incompatible CF card. The XT-CF circuit, as used on the NuXT, works with most CF cards, but a good number aren’t compatible. There is no correlation between CF card size and brand, and compatibility.
- Try another CF card
- Board damage
- Check CF slot for bent pins
- Floppy controller issues
- Bad floppy controller
- Reseat the floppy controller IC
- Resource conflict
- Ensure there are no other floppy controllers in the system

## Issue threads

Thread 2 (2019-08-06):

100% open source?

mamama1, 2019-08-06:
Hi,

awesome work! Is this 100% open source so I could in theory get all the parts and firmware by myself or would there be missing any parts?
Not that it would be very feasable... :-)

Thanks!

RigoLigoRLC, 2019-08-07:
I think it is possible. Now I'm looking for all the parts and finding a way to do it, including the VBIOS that wasn't provided with the project and the PIC MCU firmware which is also open-source. The hardware part isn't very hard though.

mamama1, 2019-08-07:
The VBIOS is probably under copyright and may be extracted from a working Trident or could probably be available somewhere on the interwebs...
Totally missed the PIC MCU, that one is for the AT/XT Keyboard interface, right?

Would be really nice if everything would be made available to make this board on your own. I highly doubt that this would lower the profit on selling the boards and kits in a significant degree cause I don't think that there are many people out there who'd go into the hassle to acquire the parts and build this totally from scratch by themselves.

For me it isn't to save money but because it is fun for me to acquire everything by myself instead of buying a kit or let alone a finished product. I'd like to still support the creator of this project somehow.

RigoLigoRLC, 2019-08-07:
Now I found the VBIOS, just through searching online. That one was easy. AT2XT is also a open sourced GitHub repo which you can just download and compile, so that's not really a problem.

I'm also trying to make it on my own, but this time it's really for saving costs. I live in China where most of the components were just available online for a resonable price and shipping fee :p but also for fun. I'm preparing these stuff so maybe sometime I can add some tips in README or somewhere else by a pull-request for others to make the kit on their own.

monotech, 2019-08-14:
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

Hello
I do sell kits and assembled boards. The main rare chip is the TVGA9000i, and stock depends on how many of those I have.
https://monotech.fwscart.com/NuXT_-_MicroATX_Turbo_XT_-_955MHz,_832K_RAM,_XT-CF,_SVGA,_Floppy,_Serial/p6083514_19777986.aspx

Closed 2021-09-18.

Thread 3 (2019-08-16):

CGA 40x25 mode

eltair, 2019-08-16:
I have an official IBM CGA card and would like the system to boot in 40 column mode, but the switch for that doesn't seem to work. The machine always boots in 80 column mode. I can switch to 40 columns successfully from dos using the mode 40 command. Any ideas? Thank you.

eltair, 2019-09-17:
FYI, I'm no longer using the CGA card with this board, although I'm still curious what the switches for video card type actually do. They don't seem to have any effect on my system.

skiselev, 2019-09-17:
It's a bug.... The BIOS was initially written for Xi 8088, which has only one switch (monochrome/color). And so it ignores the 40x25 mode.
I've created an issue for the BIOS: https://github.com/skiselev/8088_bios/issues/3

skiselev, 2019-09-19:
I've committed the fix for this issue to the BIOS repository. It will be available in the next BIOS release:
https://github.com/skiselev/8088_bios/commit/d95b9110b5713eecce2dcd4c15e561234f214daa

skiselev, 2019-09-26:
The fix is released in v0.9.7 https://github.com/skiselev/8088_bios/commit/08c673eb063bd22bcfc3bcb5bacfad20ed8876e8

eltair, 2019-09-26:
@skiselev Thanks for fixing this! I tested it and it works, although I have another issue with CGA booting that I will submit separately.

Closed 2019-09-27.

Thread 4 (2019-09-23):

A variant with Tandy 1000 / PCjr compatibility?

volkertb, 2019-09-23:
This is such an amazing project! 😍

I was wondering, however. Would it be possible to develop a variant of the NuXT board that offered compatibility with Tandy 1000 and IBM PCJr computers, particularly the graphics and sound capabilities of those systems?

I reckon integrating the sound part would be relatively easy, since one could simply integrate an existing available design such as the [Lo-tech Tandy Compatible Sound Adapter](https://www.lo-tech.co.uk/wiki/Lo-tech_Tandy_Compatible_Sound_Adapter) into such NuXT motherboard variant.

I expect that the graphics part would pose a much bigger challenge. There are no existing open source and/or DIY projects for a Tandy 1000 compatible graphics adapter or controller that I'm aware of. The fact that this graphics standard is reliant on shared memory in the first 128KB of the 640KB conventional memory range would make it even more challenging. Perhaps this would require the use of dual ported RAM, at least for the first 128KB of RAM. And additionally, some circuitry would be required to map some of that memory to address 0xB8000 for CGA compatibility. And then there is the matter of subtle compatibility issues between PCJr and Tandy 1000 graphics controllers. Ideally, we'd want such a NuXT board to offer compatibility with both systems as best as possible. I'm no expert, but this would probably require an FPGA-based graphics controller. The obvious output ports would be a RGB TTL DB9 port for CGA monitors and an NTSC composite video port, which would also allow the display of 16 color composite mode CGA graphics, if the CGA compatibility of such a solution were good enough. There are already solutions out there to convert CGA/Tandy signals to something more modern, should people need it.

Anyway, perhaps it would be something to consider. It would better justify an on-board graphics solution, due to the shared memory requirement. It would perhaps also be more "era-appropriate" than a VGA chip.

What do you think? Is this a crazy idea? As popular as the NuXT product already is, releasing a Tandy 1000 compatible variant would cause even more retro computing and gaming enthusiasts to take notice.

As a possible less ambitious alternative suggestion: perhaps a separate ISA card could be designed that would offer this compatibility (both graphics and sound) with the NuXT board, if the board could somehow allow the video memory of such a card to be mapped to both the lower part of the system RAM (up to 128KB) and the 0xB8000 memory range for CGA compatibility.

What do you all think? Crazy? Doable? Or both? 🙂

At any rate, thanks for producing this awesome piece of retro kit. Keep on tinkering!

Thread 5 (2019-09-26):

CGA cold boot

eltair, 2019-09-26:
Cold booting the machine with the onboard VGA disabled and an IBM CGA card, no output is displayed on the monitor. If I wait a bit and reset, the machine boots correctly with CGA output. If I try to reset too quickly I get no output, so maybe the CGA card just hasn't had enough time to initialize?

skiselev, 2019-09-27:
Weird. I've actually tested my Micro 8088 (not a NuXT) with CGA, and it works properly as long as I have the DIP switches set correctly. If the switches are not set correctly, for example they set to "VGA/EGA/None" instead of CGA 40x25 or CGA 80x25, it will show garbled text on the screen. Not sure the on-board VGA (although disabled) somehow interferes with CGA.

eltair, 2019-09-27:
Interesting. Even weirder, mine actually works fine with the onboard VGA enabled, and doesn't exhibit the cold boot problem.

jalgithub, 2022-08-13:
I can confirm this problem. Booting the NuXT with an ATi Small Wonder rev 2 doesn't display anything, though the monitor is clearly driven (screen is black, as opposed to white when not driven). I have to wait about 10 seconds, then warm reboot für the CGA to work.

explit7, 2024-07-20:
This is exact the same issue, which i have on my Micro8088:
[https://github.com/skiselev/8088_bios/issues/73](url)

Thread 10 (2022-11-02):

Test and certify GLaBIOS as an open-source BIOS to ship with the NuXT?

volkertb, 2022-11-02:
[GLaBIOS](https://github.com/640-KB/GLaBIOS) is an open-source BIOS for IBM PCs and clones wih 8088 and V20 CPUs. It also explicitly supports so-called "turbo" clones that have software-switchable clock speeds. At first glance, It would seem like an ideal fit for the NuXT. Has anybody tried testing compatibility yet?

skiselev, 2022-11-02:
NuXT will likely boot with GLaBIOS without any modifications.
It will have several limitations:
- GLaBIOS does not support turbo mode switching for FE2010A chipset
- GLaBIOS does not support high-density floppy drives (1.2MB, 1.44MB, 2.88MB), so the on-board FDC would be underutilized
There are other, less relevant limitations too, like a lack of RTC support, or a BIOS configuration utility.

Other than that, NuXT already ships with another [open source BIOS](https://github.com/skiselev/8088_bios) :)

640-KB, 2022-11-02:
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

Absolutely correct about the RTC, high-density floppy and BIOS configuration utility (though it does support turbo switching on the FE2010A), so no it's not a drop-in replacement for Sergey's excellent 8088_bios here. :)

That said, for anyone who would like to try it, would be really awesome to get more FE2010A testing on the NuXT.  Here's are the links for the 0.2.0-beta [8088](https://github.com/640-KB/GLaBIOS/releases/download/v0.2.0-beta/GLABIOS_0.2.0b_8F.ROM) and [V20](https://github.com/640-KB/GLaBIOS/releases/download/v0.2.0-beta/GLABIOS_0.2.0b_VP.ROM) builds.

Happy to help out any way I can!

640-KB, 2023-02-22:
Here's an update on this.  Over the past few months [GLaBIOS](https://github.com/640-KB/GLaBIOS) has been tested on NuXT/micro_8088 hardware and appears stable.

The RTC is now supported and included in the [build images](https://github.com/640-KB/GLaBIOS/releases/tag/v0.2.3) which also include the standard NuXT XUB and Multi-Floppy BIOS for high-density floppy drive support.

Currently not fully supported is NuXT/micro_8088 BIOS configuration at POST and full [Enhanced keyboard support](https://github.com/640-KB/GLaBIOS/issues/10) via AT to XT converter (this is a roadmap item).

As a NuXT owner myself (my build [pic](https://user-images.githubusercontent.com/23486433/220713233-b070e77f-7521-47bf-bbd6-a7dcfbd35482.jpg), [pic](https://user-images.githubusercontent.com/23486433/220713101-e69c2e0c-95bb-4bfd-a751-a48872c4cd4b.jpg)), am enjoying working with the advanced hardware and @skiselev has graciously blessed the continued work on this so it is entirely possible those features may be added in the future.  In the meantime, would welcome any thoughts or feedback to make GLaBIOS better for this and other platforms as well.

Builds:
https://github.com/640-KB/GLaBIOS/releases

Thanks!

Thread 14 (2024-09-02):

Beeping on and off and not booting up

ktoczyski, 2024-09-02:
Hello,

I built this project but I have a problem to run it up. Only beeping on and off, flashing BUS diode (red/green) and not booting up.

What I checked:

1. Voltages - ok
2. CPU (three different}
3. CLK on FE2010A pin 19 (is 4.77MHz)
4. CLK on CPU pin 19 (is 4.77MHz)
5. OSC on FE2010A pin 20 (is 14.3MHz)
6. CRYSTAL OUT on FE2010A pin 21 (is 28.6MHz)
7. OSC on ISA SLOT pin 30 (is 14.3MHz)
8. CLK on ISA SLOT pin 20 (is 4.77MHz)
9. POST CODE CARD - hang on code 3b (Is there a list of codes for XT_BIOS somewhere?)

Do you have any idea or suggestion where the problem might be?

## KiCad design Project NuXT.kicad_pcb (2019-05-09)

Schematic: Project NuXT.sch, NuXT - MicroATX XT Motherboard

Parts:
C1, C2, C3, C4, C5, C6, C9, C10, C12, C13, C15, C16, C17, C19, C31, C33, C36, C40, C46, C47, C48, C49, C50, C51, C52, C58, C59, C60, C63, C64, C65, C66, C67, C68, C70, C71, C72, C73, C74, C76, C77, C78, C85, C86: 100nF; C_Disc_D4.3mm_W1.9mm_P5.00mm
C8, C20, C21, C23, C24, C25, C26, C27, C28, C29, C30, C35, C56, C57, C61, C62, C69, C75, C79, C80, C81: 10uF; C_Disc_D4.3mm_W1.9mm_P5.00mm
C11, C38, C41, C42, C43, C44, C45, C54, C55, C87: 47pF; C_Disc_D4.3mm_W1.9mm_P5.00mm
C14: 5-30pF; C_Disc_D4.3mm_W1.9mm_P5.00mm
C18, C82, C83: 22pF; C_Disc_D4.3mm_W1.9mm_P5.00mm
C22: 10nF; C_Disc_D4.3mm_W1.9mm_P5.00mm
C34: 1uF; C_Disc_D4.3mm_W1.9mm_P5.00mm
C37: 100pF; C_Disc_D4.3mm_W1.9mm_P5.00mm
C39: 470pF; C_Disc_D4.3mm_W1.9mm_P5.00mm
C53: 1nF; C_Disc_D4.3mm_W1.9mm_P5.00mm
C84: 4.7nF; C_Disc_D4.3mm_W1.9mm_P5.00mm
D1, D4, D5: 1N4148; D_DO-34_SOD68_P7.62mm_Horizontal
D3: Bus Activity; LED_D3.0mm
D6: CF Activity; LED_D3.0mm
D7: 5VSB; LED_D3.0mm
D8: +5V; LED_D3.0mm
D9: +12V; LED_D3.0mm
D10: -12V; LED_D3.0mm
D11: -5V; LED_D3.0mm
F1: 1.1A; C_Disc_D4.3mm_W1.9mm_P5.00mm
FB1, FB2, FB3, FB4, FB5, FB6: BEAD; R_Axial_DIN0204_L3.6mm_D1.6mm_P7.62mm_Horizontal
HOLE1, HOLE2, HOLE3, HOLE4, HOLE5, HOLE6: HOLE; MountingHole_4mm_Pad_Via
ISA1, ISA2, ISA3, ISA4: BUSPC_HOST; Conn_Edge_ISA8_Longpads
JP1: UART Config; PinHeader_2x08_P2.54mm_Vertical
L1: 2.7uH; R_Axial_DIN0207_L6.3mm_D2.5mm_P7.62mm_Horizontal
L2, L3: 5.7uH; R_Axial_DIN0207_L6.3mm_D2.5mm_P7.62mm_Horizontal
LOGO1: SYM_Arrow45_Large; Monotech Logo 18mm
LOGO2: SYM_Arrow45_Large; Monotech Logo 92mm
P1: Front Panel; PinHeader_2x05_P2.54mm_Horizontal
P2: Speaker; PinHeader_1x04_P2.54mm_Horizontal
P3: ATX Power; Molex_Mini-Fit_Jr_5569-20A2_2x10_P4.20mm_Horizontal
P4: Floppy; Pin_Header_Straight_2x17_Pitch2.54mm_shrouded
P5: PS/2 Keyboard; Conn_Mini_DIN_6pin
P6: Serial Port; Conn_Dsub_DE9M
P7: VGA Port; DSUB-15-HD_Female_Horizontal_CONNFLY_DS1308
P8: CF_CARD; CF_Slot_3M_N7E50-7516TS0884
Q1: PN2222 EBC; TO-92L_Inline_Wide
R1, R15: 470; R_Axial_DIN0207_L6.3mm_D2.5mm_P7.62mm_Horizontal
R2, R33: 1M; R_Axial_DIN0207_L6.3mm_D2.5mm_P7.62mm_Horizontal
R3, R11, R14, R16, R31: 10K; R_Axial_DIN0207_L6.3mm_D2.5mm_P7.62mm_Horizontal
R4, R5: 47; R_Axial_DIN0207_L6.3mm_D2.5mm_P7.62mm_Horizontal
R6, R7, R8, R12, R13, R18, R29, R30: 1K; R_Axial_DIN0207_L6.3mm_D2.5mm_P7.62mm_Horizontal
R9, R21, R22: 33; R_Axial_DIN0207_L6.3mm_D2.5mm_P7.62mm_Horizontal
R10, R20, R26, R27: 4.7K; R_Axial_DIN0207_L6.3mm_D2.5mm_P7.62mm_Horizontal
R17: 100; R_Axial_DIN0207_L6.3mm_D2.5mm_P7.62mm_Horizontal
R19, R23, R24, R25: 150; R_Axial_DIN0207_L6.3mm_D2.5mm_P7.62mm_Horizontal
R28: 5.6K; R_Axial_DIN0207_L6.3mm_D2.5mm_P7.62mm_Horizontal
R32: 1.5K; R_Axial_DIN0207_L6.3mm_D2.5mm_P7.62mm_Horizontal
RN1: 4.7K; R_Array_SIP9
RN2, RN3, RN6, RN14, RN15: 10K; R_Array_SIP9
RN4, RN5, RN12: 4.7K; R_Array_SIP7
RN13: 1K; R_Array_SIP7
SP1: Speaker; MagneticBuzzer_ProSignal_ABT-410-RC
SW1: System Config; SW_DIP_SPSTx10_Slide_9.78x27.58mm_W7.62mm_P2.54mm
SW2: UMB Config; SW_DIP_SPSTx05_Slide_9.78x14.88mm_W7.62mm_P2.54mm
SW3: ROM Socket Address; SW_DIP_SPSTx04_Slide_9.78x12.34mm_W7.62mm_P2.54mm
SW4: U35 ROM Size; SW_MS-22D18G2
SW5: Power; SW_PUSH_6mm
SW6: Reset; SW_PUSH_6mm
U1: 8088; DIP-40_W15.24mm_Socket
U2: 8087; DIP-40_W15.24mm_Socket
U3: SST39SF010A; DIP-32_W15.24mm_Socket
U4, U5: AS6C4008; SSOP-32_11.305x20.495mm_P1.27mm
U6: FE2010A; PLCC-84_THT-Socket
U7: ATF16V8B; DIP-20_W7.62mm_Socket
U9: PIC12F629; DIP-8_W7.62mm_Socket
U10, U11, U12: 74F573; DIP-20_W7.62mm
U13, U14: 74F245; DIP-20_W7.62mm
U15, U16: 74F244; DIP-20_W7.62mm
U17: 74LS14; DIP-14_W7.62mm
U18: 74LS74; DIP-14_W7.62mm
U19: 7905; TO220-3_Soldertab
U20: TVGA9000i; PQFP-160_28x28mm_P0.65mm_LongPads
U21: 27C256; DIP-28_W15.24mm_Socket
U22, U23, U24, U25: 256Kx4 70ns; DIP-20_W7.62mm_Socket
U26, U36: 74LS688; DIP-20_W7.62mm
U27: 74LS32; DIP-14_W7.62mm
U28: 74LS04; DIP-14_W7.62mm
U29: 82077AA/PC8477; PLCC-68_THT-Socket
U30: 16(C)x50; PLCC-44_THT-Socket
U31: GD75232/75(C)185; DIP-20_W7.62mm
U32, U33: 74LS138; DIP-16_W7.62mm
U35: 28C64B/28C256; DIP-28_W15.24mm_Socket
X1: 28.63636MHz; Crystal_HC49-4H_Vertical
X2: 40MHz; Crystal_HC49-4H_Vertical
X3: 1.8432MHz TTL; Oscillator_DIP-14
X4: 24MHz; Crystal_HC49-4H_Vertical
X5: 1.8432MHz; Crystal_HC49-U_Horizontal_Solderpad

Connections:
/0x2E8: JP1.9, U32.11 (~Y4)
/0x2F8: JP1.13, U32.9 (~Y6)
/0x3E8: JP1.11, U32.10 (~Y5)
/0x3F0: SW1.16, U32.12 (~Y3)
/0x3F8: JP1.15, U32.7 (~Y7)
/5VSB: C29.1, C31.1, C33.1, D4.1 (K), D5.1 (K), D7.2 (A), P3.9 (5VSB), R14.1, R16.1, U17.9, U17.11, U17.13, U17.14 (VCC), U18.1 (~R), U18.10 (~S), U18.13 (~R), U18.14 (VCC)
/12V: C30.1, C73.1, C75.1, D9.2 (A), ISA1.9 (+12V), ISA2.9 (+12V), ISA3.9 (+12V), ISA4.9 (+12V), P3.10 (12V), U31.1 (VDD)
/-5V: C28.2, D11.1 (K), ISA1.5 (-5V), ISA2.5 (-5V), ISA3.5 (-5V), ISA4.5 (-5V), U19.3 (OUT)
/-12V: C24.2, C78.2, C79.2, D10.1 (K), ISA1.7 (-12V), ISA2.7 (-12V), ISA3.7 (-12V), ISA4.7 (-12V), P3.12 (-12V), U19.2 (IN), U31.10 (VSS)
/A0: ISA1.62 (SA0), ISA2.62 (SA0), ISA3.62 (SA0), ISA4.62 (SA0), U3.12 (A0), U4.12 (A0), U5.12 (A0), U10.19 (O0), U20.135 (SA0), U29.7 (A0), U30.31 (A0), U35.10 (A0)
/A1: ISA1.61 (SA1), ISA2.61 (SA1), ISA3.61 (SA1), ISA4.61 (SA1), P8.20 (A0), U3.11 (A1), U4.11 (A1), U5.11 (A1), U10.18 (O1), U20.136 (SA1), U21.10 (A0), U29.8 (A1), U30.30 (A1), U35.9 (A1)
/A2: ISA1.60 (SA2), ISA2.60 (SA2), ISA3.60 (SA2), ISA4.60 (SA2), P8.19 (A1), U3.10 (A2), U4.10 (A2), U5.10 (A2), U10.17 (O2), U20.137 (SA2), U21.9 (A1), U29.10 (A2), U30.29 (A2), U35.8 (A2)
/A3: ISA1.59 (SA3), ISA2.59 (SA3), ISA3.59 (SA3), ISA4.59 (SA3), P8.18 (A2), U3.9 (A3), U4.9 (A3), U5.9 (A3), U10.16 (O3), U20.138 (SA3), U21.8 (A2), U32.3 (C), U35.7 (A3)
/A4: ISA1.58 (SA4), ISA2.58 (SA4), ISA3.58 (SA4), ISA4.58 (SA4), U3.8 (A4), U4.8 (A4), U5.8 (A4), U10.15 (O4), U20.139 (SA4), U21.7 (A3), U27.4, U28.1, U32.2 (B), U35.6 (A4)
/A5: ISA1.57 (SA5), ISA2.57 (SA5), ISA3.57 (SA5), ISA4.57 (SA5), U3.7 (A5), U4.7 (A5), U5.7 (A5), U10.14 (O5), U20.140 (SA5), U21.6 (A4), U26.2 (P0), U32.6 (G1), U35.5 (A5)
/A6: ISA1.56 (SA6), ISA2.56 (SA6), ISA3.56 (SA6), ISA4.56 (SA6), U3.6 (A6), U4.6 (A6), U5.6 (A6), U10.13 (O6), U20.141 (SA6), U21.5 (A5), U26.4 (P1), U33.1 (A), U35.4 (A6)
/A7: ISA1.55 (SA7), ISA2.55 (SA7), ISA3.55 (SA7), ISA4.55 (SA7), R12.1, U3.5 (A7), U4.5 (A7), U5.5 (A7), U10.12 (O7), U20.142 (SA7), U21.4 (A6), U26.6 (P2), U33.2 (B), U35.3 (A7)
/A8: ISA1.54 (SA8), ISA2.54 (SA8), ISA3.54 (SA8), ISA4.54 (SA8), U3.27 (A8), U4.27 (A8), U5.27 (A8), U11.19 (O0), U20.144 (SA8), U21.3 (A7), U26.8 (P3), U32.1 (A), U35.25 (A8)
/A9: ISA1.53 (SA9), ISA2.53 (SA9), ISA3.53 (SA9), ISA4.53 (SA9), U3.26 (A9), U4.26 (A9), U5.26 (A9), U11.18 (O1), U20.145 (SA9), U21.25 (A8), U26.11 (P4), U33.3 (C), U35.24 (A9)
/A10: ISA1.52 (SA10), ISA2.52 (SA10), ISA3.52 (SA10), ISA4.52 (SA10), U3.23 (A10), U4.23 (A10), U5.23 (A10), U11.17 (O2), U20.146 (SA10), U21.24 (A9), U35.21 (A10)
/A11: ISA1.51 (SA11), ISA2.51 (SA11), ISA3.51 (SA11), ISA4.51 (SA11), U3.25 (A11), U4.25 (A11), U5.25 (A11), U11.16 (O3), U20.147 (SA11), U21.21 (A10), U35.23 (A11)
/A12: ISA1.50 (SA12), ISA2.50 (SA12), ISA3.50 (SA12), ISA4.50 (SA12), U3.4 (A12), U4.4 (A12), U5.4 (A12), U11.15 (O4), U20.148 (SA12), U21.23 (A11), U35.2 (A12)
/A13: ISA1.49 (SA13), ISA2.49 (SA13), ISA3.49 (SA13), ISA4.49 (SA13), SW4.5 (B), U3.28 (A13), U4.28 (A13), U5.28 (A13), U11.14 (O5), U20.149 (SA13), U21.2 (A12), U35.26 (A13)
/A14: ISA1.48 (SA14), ISA2.48 (SA14), ISA3.48 (SA14), ISA4.48 (SA14), SW4.2 (B), U3.29 (A14), U4.3 (A14), U5.3 (A14), U11.13 (O6), U20.150 (SA14), U21.26 (A13), U35.1 (A14)
/A15: ISA1.47 (SA15), ISA2.47 (SA15), ISA3.47 (SA15), ISA4.47 (SA15), U3.3 (A15), U4.31 (A15), U5.31 (A15), U7.9 (I8), U11.12 (O7), U20.151 (SA15), U36.5 (R1)
/A16: ISA1.46 (SA16), ISA2.46 (SA16), ISA3.46 (SA16), ISA4.46 (SA16), U4.2 (A16), U5.2 (A16), U7.5 (I4), U12.15 (O4), U20.152 (SA16), U36.3 (R0)
/A17: ISA1.45 (SA17), ISA2.45 (SA17), ISA3.45 (SA17), ISA4.45 (SA17), U4.30 (A17), U5.30 (A17), U7.6 (I5), U12.14 (O5), U20.113 (SA17(LA17)), U36.14 (R5)
/A18: ISA1.44 (SA18), ISA2.44 (SA18), ISA3.44 (SA18), ISA4.44 (SA18), U4.1 (A18), U5.1 (A18), U7.7 (I6), U12.13 (O6), U20.114 (SA18(LA18)), U36.16 (R6)
/A19: ISA1.43 (SA19), ISA2.43 (SA19), ISA3.43 (SA19), ISA4.43 (SA19), U4.22 (~CE), U7.8 (I7), U12.12 (O7), U20.115 (SA19(LA19)), U36.18 (R7)
/AA8: U1.8 (A8), U2.8 (AD8), U6.44 (A8), U11.2 (D0)
/AA9: U1.7 (A9), U2.7 (AD9), U6.45 (A9), U11.3 (D1)
/AA10: U1.6 (A10), U2.6 (AD10), U6.46 (A10), U11.4 (D2)
/AA11: U1.5 (A11), U2.5 (AD11), U6.47 (A11), U11.5 (D3)
/AA12: U1.4 (A12), U2.4 (AD12), U6.48 (A12), U11.6 (D4)
/AA13: U1.3 (A13), U2.3 (AD13), U6.49 (A13), U11.7 (D5)
/AA14: U1.2 (A14), U2.2 (AD14), U6.50 (A14), U11.8 (D6)
/AA15: U1.39 (A15), U2.39 (AD15), U6.51 (A15), U11.9 (D7)
/AA16: U1.38 (A16/S3), U2.38 (A16/S3), U6.52 (A16), U12.6 (D4)
/AA17: U1.37 (A17/S4), U2.37 (A17/S4), U6.53 (A17), U12.7 (D5)
/AA18: U1.36 (A18/S5), U2.36 (A18/S5), U6.54 (A18), U12.8 (D6)
/AA19: U1.35 (A19/S6), U2.35 (A19/S6), U6.55 (A19), U12.9 (D7)
/AD0: U1.16 (AD0), U2.16 (AD0), U3.13 (DQ0), U6.34 (AD0), U10.2 (D0), U13.2 (A1)
/AD1: U1.15 (AD1), U2.15 (AD1), U3.14 (DQ1), U6.35 (AD1), U10.3 (D1), U13.3 (A2)
/AD2: U1.14 (AD2), U2.14 (AD2), U3.15 (DQ2), U6.36 (AD2), U10.4 (D2), U13.4 (A3)
/AD3: U1.13 (AD3), U2.13 (AD3), U3.17 (DQ3), U6.37 (AD3), U10.5 (D3), U13.5 (A4)
/AD4: U1.12 (AD4), U2.12 (AD4), U3.18 (DQ4), U6.38 (AD4), U10.6 (D4), U13.6 (A5)
/AD5: U1.11 (AD5), U2.11 (AD5), U3.19 (DQ5), U6.39 (AD5), U10.7 (D5), U13.7 (A6)
/AD6: U1.10 (AD6), U2.10 (AD6), U3.20 (DQ6), U6.40 (AD6), U10.8 (D6), U13.8 (A7)
/AD7: U1.9 (AD7), U2.9 (AD7), U3.21 (DQ7), U6.41 (AD7), U10.9 (D7), U13.9 (A8)
/AEN: ISA1.42 (AEN), ISA2.42 (AEN), ISA3.42 (AEN), ISA4.42 (AEN), SW1.12, SW1.15, U16.16 (Y2), U20.22 (AEN), U32.4 (~G2A)
/ALE: ISA1.28 (ALE), ISA2.28 (ALE), ISA3.28 (ALE), ISA4.28 (ALE), U15.3 (Y4)
/APNMI: U2.32 (INT), U6.29 (APNMI)
/AT_KBCLK: D1.2 (A), P5.5, RN5.3 (R2), U9.5 (GP2/T0CKI/INT/COUT)
/AT_KBDATA: P5.1, RN5.2 (R1), U9.6 (GP1/CIN-/ICSPCLK)
/AVDD1: C40.1, C56.1, C59.1, L2.2, U20.124 (AVDD1)
/AVDD2: C57.1, C60.1, L3.2, U20.6 (AVDD2), U20.13 (AVDD2)
/B: FB3.1, R25.1, U20.2 (B)
/BLUE: C45.1, FB3.2, P7.3
/CF_DMARQ: P8.43 (~INPACK), R28.1
/CF_IORDY: P8.42 (IORDY), R30.1
/CLK: ISA1.20 (CLK), ISA2.20 (CLK), ISA3.20 (CLK), ISA4.20 (CLK), R5.1
/CLK88: U1.19 (CLK), U2.19 (CLK), U6.19 (CLOCK), U15.8 (A4)
/CS_RomSocket: U35.20 (CS), U36.19 (P=R)
/CTS: P6.8, U31.7 (RA4)
/D0: ISA1.40 (SD0), ISA2.40 (SD0), ISA3.40 (SD0), ISA4.40 (SD0), P8.21 (D0), RN2.2 (R1), U13.18 (B1), U14.2 (A1), U20.25 (SD0), U29.11 (DB0), U30.2 (D0), U35.11 (D0)
/D1: ISA1.39 (SD1), ISA2.39 (SD1), ISA3.39 (SD1), ISA4.39 (SD1), P8.22 (D1), RN2.3 (R2), U13.17 (B2), U14.3 (A2), U20.26 (SD1), U29.13 (DB1), U30.3 (D1), U35.12 (D1)
/D2: ISA1.38 (SD2), ISA2.38 (SD2), ISA3.38 (SD2), ISA4.38 (SD2), P8.23 (D2), RN2.4 (R3), U13.16 (B3), U14.4 (A3), U20.27 (SD2), U29.14 (DB2), U30.4 (D2), U35.13 (D2)
/D3: ISA1.37 (SD3), ISA2.37 (SD3), ISA3.37 (SD3), ISA4.37 (SD3), P8.2 (D3), RN2.5 (R4), U13.15 (B4), U14.5 (A4), U20.28 (SD3), U29.15 (DB3), U30.5 (D3), U35.15 (D3)
/D4: ISA1.36 (SD4), ISA2.36 (SD4), ISA3.36 (SD4), ISA4.36 (SD4), P8.3 (D4), RN2.6 (R5), U13.14 (B5), U14.6 (A5), U20.29 (SD4), U29.17 (DB4), U30.6 (D4), U35.16 (D4)
/D5: ISA1.35 (SD5), ISA2.35 (SD5), ISA3.35 (SD5), ISA4.35 (SD5), P8.4 (D5), RN2.7 (R6), U13.13 (B6), U14.7 (A6), U20.30 (SD5), U29.19 (DB5), U30.7 (D5), U35.17 (D5)
/D6: ISA1.34 (SD6), ISA2.34 (SD6), ISA3.34 (SD6), ISA4.34 (SD6), P8.5 (D6), RN2.8 (R7), U13.12 (B7), U14.8 (A7), U20.31 (SD6), U29.20 (DB6), U30.8 (D6), U35.18 (D6)
/D7: ISA1.33 (SD7), ISA2.33 (SD7), ISA3.33 (SD7), ISA4.33 (SD7), P8.6 (D7), RN2.9 (R8), U13.11 (B8), U14.9 (A8), U20.32 (SD7), U29.22 (DB7), U30.9 (D7), U35.19 (D7)
/DCD: P6.1, U31.2 (RA1)
/DENSL: P4.2, U29.49 (DENSEL)
/DIR: U6.72 (DTR), U13.1 (DIR)
/DRQ1: ISA1.18 (DRQ1), ISA2.18 (DRQ1), ISA3.18 (DRQ1), ISA4.18 (DRQ1), U6.58 (DRQ1)
/DRQ2: ISA1.6 (DRQ2), ISA2.6 (DRQ2), ISA3.6 (DRQ2), ISA4.6 (DRQ2), U6.57 (DRQ2), U29.24 (DRQ)
/DRQ3: ISA1.16 (DRQ3), ISA2.16 (DRQ3), ISA3.16 (DRQ3), ISA4.16 (DRQ3), U6.56 (DRQ3)
/DSA: P4.14, U29.58 (DS0)
/DSB: P4.12, U29.62 (DS1)
/DSKCG: P4.34, RN13.6 (R5), U29.31 (DSKCHG)
/DSR: P6.6, U31.3 (RA2)
/DTR: P6.4, U31.8 (DY3)
/E0_PASS: RN15.4 (R3), SW1.3, U9.4 (GP3/~MCLR~/Vpp)
/EN_RomSocket: RN6.2 (R1), SW1.9, U36.1 (G)
/EOP: U6.59 (EOP), U15.4 (A2)
/FloppyDIR: P4.18, U29.56 (DIR)
/G: FB2.1, R24.1, U20.3 (G)
/GREEN: C44.1, FB2.2, P7.2
/HDD_LED_Ext: P1.3, U28.10
/HDSEL: P4.32, U29.51 (HDSEL)
/HSYNC: FB5.2, U20.48 (HSYNC)
/INDEX: P4.8, RN13.2 (R1), U29.26 (INDX)
/INT: U1.18 (INTR), U6.10 (INT)
/IORDY: ISA1.41 (IO_READY), ISA2.41 (IO_READY), ISA3.41 (IO_READY), ISA4.41 (IO_READY), U6.28 (IORDY), U20.157 (IOCHRDY)
/IRQ2: ISA1.4 (IRQ2), ISA2.4 (IRQ2), ISA3.4 (IRQ2), ISA4.4 (IRQ2), U6.76 (IRQ2)
/IRQ3: ISA1.25 (IRQ3), ISA2.25 (IRQ3), ISA3.25 (IRQ3), ISA4.25 (IRQ3), JP1.1, U6.77 (IRQ3)
/IRQ4: ISA1.24 (IRQ4), ISA2.24 (IRQ4), ISA3.24 (IRQ4), ISA4.24 (IRQ4), JP1.3, U6.78 (IRQ4)
/IRQ5: ISA1.23 (IRQ5), ISA2.23 (IRQ5), ISA3.23 (IRQ5), ISA4.23 (IRQ5), JP1.5, U6.79 (IRQ5)
/IRQ6: ISA1.22 (IRQ6), ISA2.22 (IRQ6), ISA3.22 (IRQ6), ISA4.22 (IRQ6), U6.80 (IRQ6), U29.23 (INT)
/IRQ7: ISA1.21 (IRQ7), ISA2.21 (IRQ7), ISA3.21 (IRQ7), ISA4.21 (IRQ7), JP1.7, U6.81 (IRQ7)
/KBCLK: RN5.4 (R3), U6.25 (KBCLK), U9.2 (GP5/T1CKI/OSC1/CLKIN)
/KBDATA: RN5.5 (R4), U6.26 (KBDA), U9.3 (GP4/~T1G~/OSC2/CLKOUT)
/KBD_VCC: F1.1, P5.4
/LE: U6.70 (ALE), U10.11 (LE), U11.11 (LE), U12.11 (LE)
/MAA0: U20.52 (MAA0), U22.6 (A0), U24.6 (A0)
/MAA1: U20.53 (MAA1), U22.7 (A1), U24.7 (A1)
/MAA2: U20.54 (MAA2), U22.8 (A2), U24.8 (A2)
/MAA3: U20.55 (MAA3), U22.9 (A3), U24.9 (A3)
/MAA4: U20.56 (MAA4), U22.11 (A4), U24.11 (A4)
/MAA5: U20.57 (MAA5), U22.12 (A5), U24.12 (A5)
/MAA6: U20.59 (MAA6), U22.13 (A6), U24.13 (A6)
/MAA7: U20.60 (MAA7), U22.14 (A7), U24.14 (A7)
/MAA8: U20.61 (MAA8), U22.15 (A8), U24.15 (A8)
/MAB0: U20.73 (MAB0), U23.6 (A0), U25.6 (A0)
/MAB1: U20.74 (MAB1), U23.7 (A1), U25.7 (A1)
/MAB2: U20.75 (MAB2), U23.8 (A2), U25.8 (A2)
/MAB3: U20.76 (MAB3), U23.9 (A3), U25.9 (A3)
/MAB4: U20.77 (MAB4), U23.11 (A4), U25.11 (A4)
/MAB5: U20.78 (MAB5), U23.12 (A5), U25.12 (A5)
/MAB6: U20.82 (MAB6), U23.13 (A6), U25.13 (A6)
/MAB7: U20.83 (MAB7), U23.14 (A7), U25.14 (A7)
/MAB8: U20.84 (MAB8), U23.15 (A8), U25.15 (A8)
/MD0: U4.13 (DQ0), U5.13 (DQ0), U14.18 (B1)
/MD1: U4.14 (DQ1), U5.14 (DQ1), U14.17 (B2)
/MD2: U4.15 (DQ2), U5.15 (DQ2), U14.16 (B3)
/MD3: U4.17 (DQ3), U5.17 (DQ3), U14.15 (B4)
/MD4: U4.18 (DQ4), U5.18 (DQ4), U14.14 (B5)
/MD5: U4.19 (DQ5), U5.19 (DQ5), U14.13 (B6)
/MD6: U4.20 (DQ6), U5.20 (DQ6), U14.12 (B7)
/MD7: U4.21 (DQ7), U5.21 (DQ7), U14.11 (B8)
/MEA: P4.10, U29.57 (ME0)
/MEB: P4.16, U29.61 (ME1)
/MONITOR: FB4.2, R26.1, U20.46 (MONITOR)
/NMI: U1.17 (NMI), U6.31 (NMI)
/OSC: U6.20 (OSC), U15.2 (A1)
/OSCDRV: ISA1.30 (OSC), ISA2.30 (OSC), ISA3.30 (OSC), ISA4.30 (OSC), R4.1, U20.98 (ROMCLK)
/PWR_SW: P1.6, R14.2, R15.2, SW5.2
/QS0: U1.25 (QS0), U2.25 (QS0)
/QS1: U1.24 (QS1), U2.24 (QS1)
/R: FB1.1, R23.1, U20.4 (R)
/RDATA: P4.30, RN13.5 (R4), U29.41 (RDDATA)
/READY: U1.22 (READY), U2.22 (READY), U6.17 (READY)
/RED: C43.1, FB1.2, P7.1
/RESET: U1.21 (RESET), U2.21 (RESET), U6.18 (RESET), U16.2 (A1)
/RI: P6.9, U31.9 (RA5)
/RMD0: U20.43 (RMD0), U21.11 (DQ0)
/RMD1: SW1.14, U20.39 (RMD1), U21.12 (DQ1)
/RMD2: U20.38 (RMD2), U21.13 (DQ2)
/RMD3: U20.37 (RMD3), U21.15 (DQ3)
/RMD4: RN12.3 (R2), U20.36 (RMD4), U21.16 (DQ4)
/RMD5: U20.35 (RMD5), U21.17 (DQ5)
/RMD6: RN12.2 (R1), U20.34 (RMD6), U21.18 (DQ6)
/RMD7: U20.33 (RMD7), U21.19 (DQ7)
/ROMA0: U20.97 (ROMBA0), U21.27 (A14)
/ROM_A16: R3.2, SW1.4, U3.2 (A16)
/RSTDRV: ISA1.2 (RESET), ISA2.2 (RESET), ISA3.2 (RESET), ISA4.2 (RESET), R18.1, U16.18 (Y1), U28.3, U29.32 (RESET), U30.39 (MR)
/RTS: P6.7, U31.5 (DY1)
/RX: P6.2, U31.4 (RA3)
/SIN: U30.11 (SIN), U31.17 (RY3)
/SOUT: U30.13 (SOUT), U31.15 (DA2)
/SPKR: U6.14 (SPEAKR), U7.14 (I/O6)
/STEP: P4.20, U29.55 (STEP)
/TC: ISA1.27 (TC), ISA2.27 (TC), ISA3.27 (TC), ISA4.27 (TC), U15.16 (Y2), U29.25 (TC)
/TRK00: P4.26, RN13.3 (R2), U29.2 (TRK0)
/TX: P6.3, U31.6 (DY2)
/UART_IRQ: JP1.2, JP1.4, JP1.6, JP1.8, U30.33 (INTR)
/VMD0: U20.64 (MD0), U22.1 (DQ1)
/VMD1: U20.65 (MD1), U22.2 (DQ2)
/VMD2: SW1.13, U20.66 (MD2), U22.18 (DQ3)
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

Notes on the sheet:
-5V Regulator
CPU Activity Indicator
ATX Power Connector
Mounting Holes
ATX Power On Circuit
Bypass Capacitors
ISA Bus Slots
Spare
SW2: UMB Config Default: All off 1: C0000-C7FFF 2: C8000-CFFFF 3: D0000-D7FFF 4: D8000-DFFFF 5: E0000-EFFFF
CPU Section
Spares
I/O Ports Chip Select Logic
Compact Flash Interface
XT-CF
VGA BIOS
SVGA
Fixed at 300h
Multi I/O
JP1: UART Config All open: Disabled 1: IRQ3 (COM2, COM4) 2: IRQ4 (COM1, COM3) 3: IRQ5 4: IRQ7 5: 2E8 (COM4) 6: 3E8 (COM3) 7: 2F8 (COM2) 8: 3F8 (COM1) Default: 2, 8 closed
Floppy DisK Controller
Serial Port Controller (UART)
C84 only needed for Intel FDC
NOTE: Only compatible with 28C64B 8K EEPROMs, not 28C64(non-B)
NOTE: ROM 0xC0000 - 0xDFFFF only
Boot ROM (Optional)
Remove pin 10 from header
SW1: System Config Default: 1, 2, 5, 6, 7 ON Video mode: 1 ON, 2 ON : VGA/EGA/None 1 ON, 2 OFF : 80x25 CGA 1 OFF, 2 ON : 40x25 CGA 1 OFF, 2 OFF: MDA/Hercules 3: Enable keyboard E0 scancode passthrough 4: Use 2nd half of system ROM instead of 1st half 5: Enable onboard primary floppy controller 6: E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
PSU Indicator LEDs
Optional DIP Oscillator instead of Crystal
Put serial circuitry close to bus

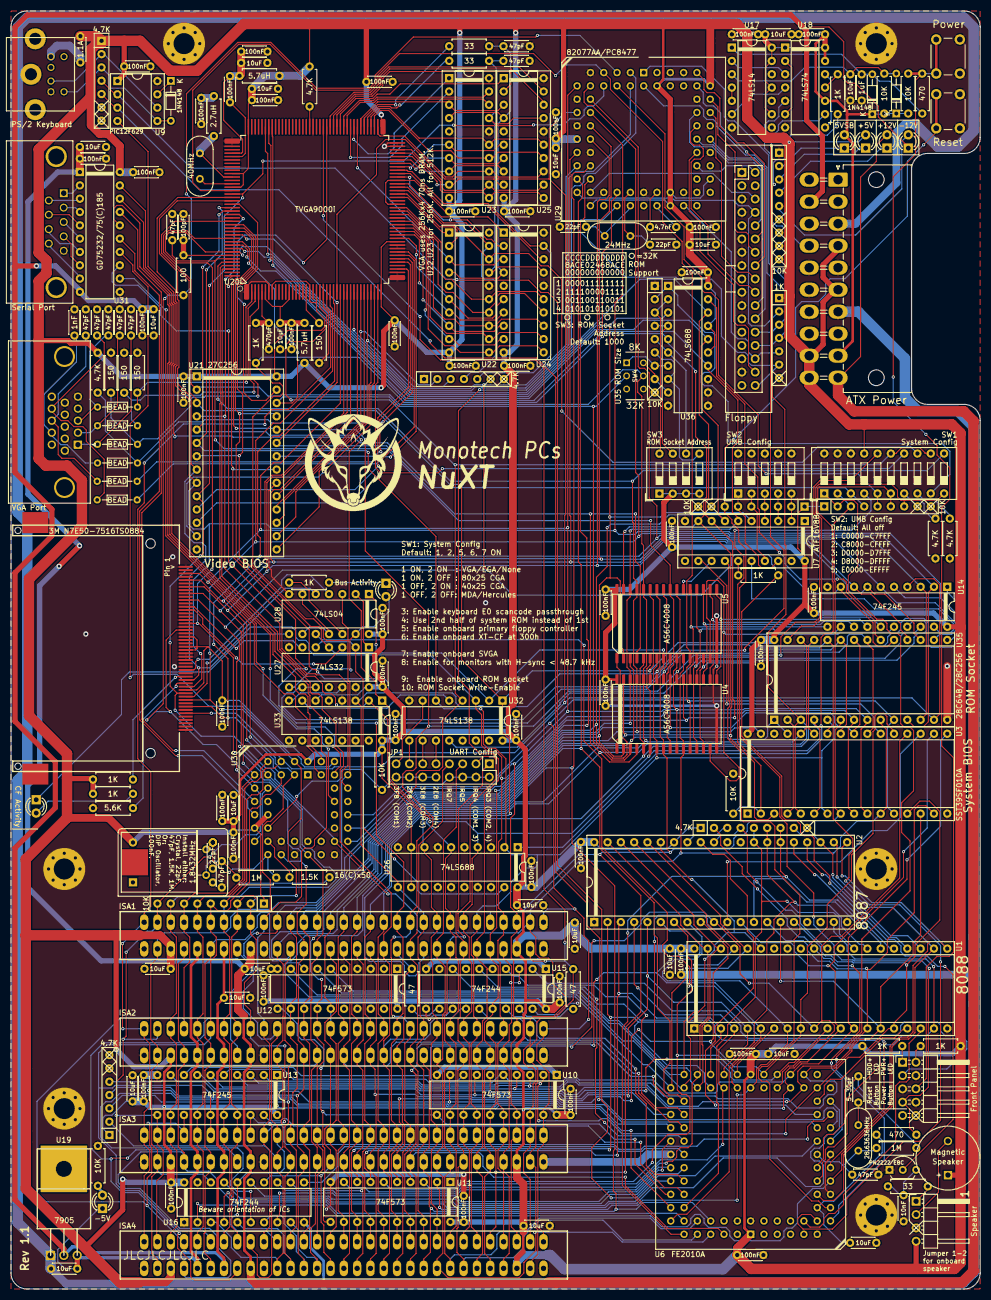
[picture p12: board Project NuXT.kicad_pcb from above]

Board: 2 copper layers, 184.9 x 243.8 mm, 216 parts (1 on the bottom side), 315 nets.
